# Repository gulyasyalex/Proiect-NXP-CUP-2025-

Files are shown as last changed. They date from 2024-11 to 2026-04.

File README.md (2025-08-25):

# Debix Smart RC Car — NXP Cup 2025
(For more Information visit Docs folder)
This project runs the **image processing** and **control logic** for the smart RC car using a **Debix Model B** with an **NXP i.MX 8M Plus** processor.  
It handles:
- Camera capture & processing (**OpenCV**)
- Pure Pursuit steering calculation
- TCP & Serial communication to the Teensy
- Optional TCP client to connect to your website for data/debug

---

## Project Structure

```
Proiect-NXP-CUP-2025-/
├── build/                # Build output for Debix C++ app
├── include/              # C++ header files and modules
├── src/                  # C++ source files
├── out/                  # (Optional) Generated output/logs
├── test/                 # Test code
├── Teensy-Code/          # Teensy firmware(separate build using Platformio)
├── VisionDebixTCP/       # Python TCP client
│   ├── TCPclient.py
├── .venv/                # Python virtual environment for TCP client
├── CMakeLists.txt        # C++ build configuration
├── debix-systemd-setup.txt # Systemd service setup instructions
└── README.md
```

---

## Requirements

**Debix Model B** running Linux  
**CMake** >= 3.15  
**g++** or Clang  
**OpenCV** installed  
**Python 3** (for TCP client)  
Teensy must be flashed separately with Platformio

---

## Build Instructions — C++ Debix App in command line

1. From the project root:
   cmake -S . -B build

2. Build the project:
   cmake --build build

3. The executable will be in `build/`:
   ./build/DEBIX

---

## Run Instructions

### ✅ Run C++ Debix App

1. Make sure:
   - USB camera is connected
   - Teensy is connected
   - ENABLE_TCP_SITE_DEBUG is 1 if you want web access / 0 if in race mode

2. Run your app:
   ./build/DEBIX

### ✅ Run Python TCP Client

1. Activate your Python virtual environment:
   source .venv/bin/activate

2. Go to your TCP client folder:
   cd VisionDebixTCP
   python TCPclient.py

---

## ⚡ Teensy Firmware

The `Teensy-Code/` folder holds your Teensy microcontroller code.  
Flash it separately using **PlatformIO**.

---

## ✅ Tips

- Use `config.h` for all kind of config settings.
- Check camera details with `v4l2-ctl --list-devices`.

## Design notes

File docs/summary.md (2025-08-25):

# Project Summary
I have a full thesis on this project in my native language. Online tools can easily translate all informations for better understanding. Thank you!
## Overview

This work presents the development of an autonomous vehicle for the NXP Cup competition, where the goal is to complete a predefined track without human intervention. The project combines both hardware components and custom-developed algorithms in order to achieve competitive performance.

For track detection, a camera mounted in the center of the car captures images in real time, processed using the OpenCV library. All image processing runs on the Debix Model B board, while a Teensy 4.0 microcontroller controls the actuators.

An important aspect of this work is the image processing pipeline (detailed in Section 4.3 of the thesis) and the use of the Bird’s Eye View technique, which improves perception of the surrounding environment. The main trajectory tracking algorithm is based on an enhanced version of Pure Pursuit (explained in Section 4.4), which relies on the midline of the track and the vehicle’s geometry. The improvement consists of dynamically adjusting the lookahead distance according to the vehicle’s speed and the curvature of the detected path.

Testing was conducted both on a custom-built track (with better grip than the competition’s) and on the official NXP Cup track. This difference in conditions initially affected system performance, but thanks to the interactive settings menu, parameters could be tuned on the day of the competition, resulting in satisfactory performance.

## Architecture

The system architecture is divided into two main components: hardware and software.

### Hardware Architecture

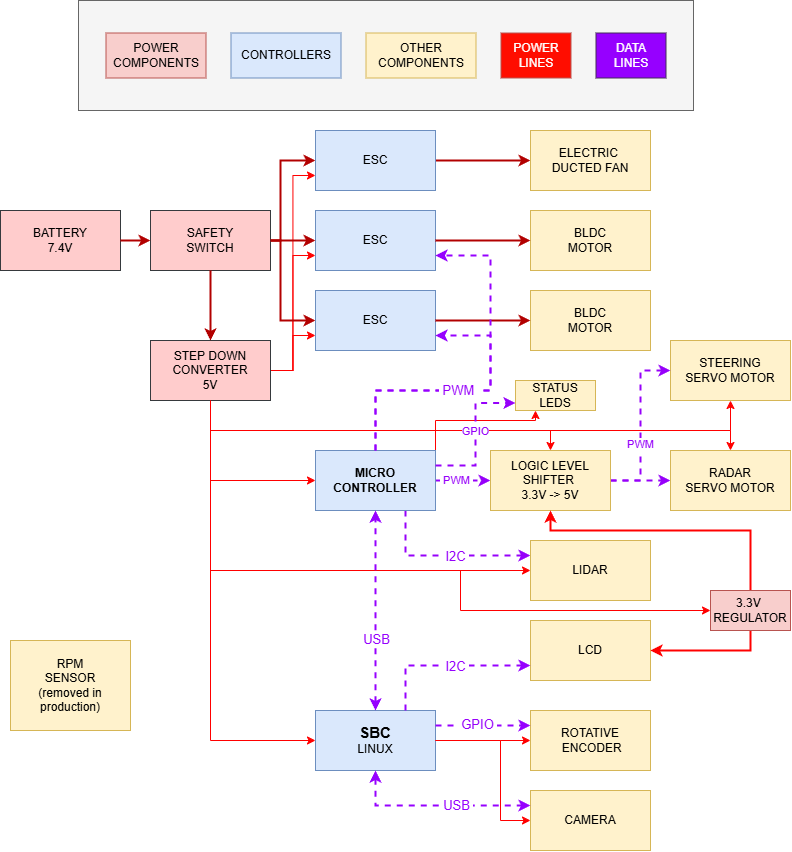
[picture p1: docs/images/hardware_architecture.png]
Hardware Architecture


Processing Unit: Debix Model B (NXP i.MX 8M Plus, ARM Cortex-A53 quad-core @ 1.6 GHz, integrated NPU up to 2.3 TOPS) running Ubuntu Linux.

Microcontroller: Teensy 4.0 used for real-time control of the servo motor and dual rear motors.

Actuators:
* Steering via SPT5613 servo motor implementing Ackermann geometry.
* Propulsion via two DC motors mounted on the rear axle.
* Additional thrust from an EDF (Electric Ducted Fan) for straight-line speed.

Sensors:
* USB UVC camera for track detection.
* LiDAR (infrared) for obstacle detection and finish-line sensing.
* Rotary encoder for speed feedback.
* OLED display + rotary encoder for interactive settings menu.

Power System: Li-Po battery with step-down converters for stable voltage supply.

### Software Architecture

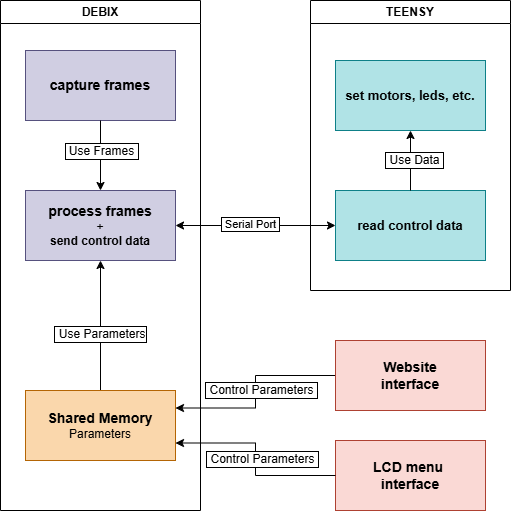
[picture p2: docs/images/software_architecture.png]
Software Architecture


The software stack is split across the Debix board and the Teensy microcontroller:

Debix Board (Linux):
* Image acquisition using OpenCV.
* Preprocessing pipeline: thresholding, skeletonization, line detection, polyline simplification, midline generation.
* Perspective transformation (Bird’s Eye View) for improved lane perception.
* Path tracking using Pure Pursuit with dynamic lookahead distance.
* TCP communication with Teensy for sending steering and speed commands.
* Interactive Python menu for adjusting parameters in real time (via shared memory and OLED display).

Teensy Microcontroller:
* Reads serial commands from the Debix.
* Generates PWM signals for the steering servo and rear motors.
* Safety features, including emergency remote stop and refresh rate control.

This modular architecture ensures real-time image processing on the Debix while leaving low-level actuator control to the Teensy, balancing performance and reliability.

## Algorithms

The software relies on a multi-stage pipeline for perception and control. The main steps are lane detection, Bird’s Eye View transformation, and path tracking with Pure Pursuit.

### Lane Detection

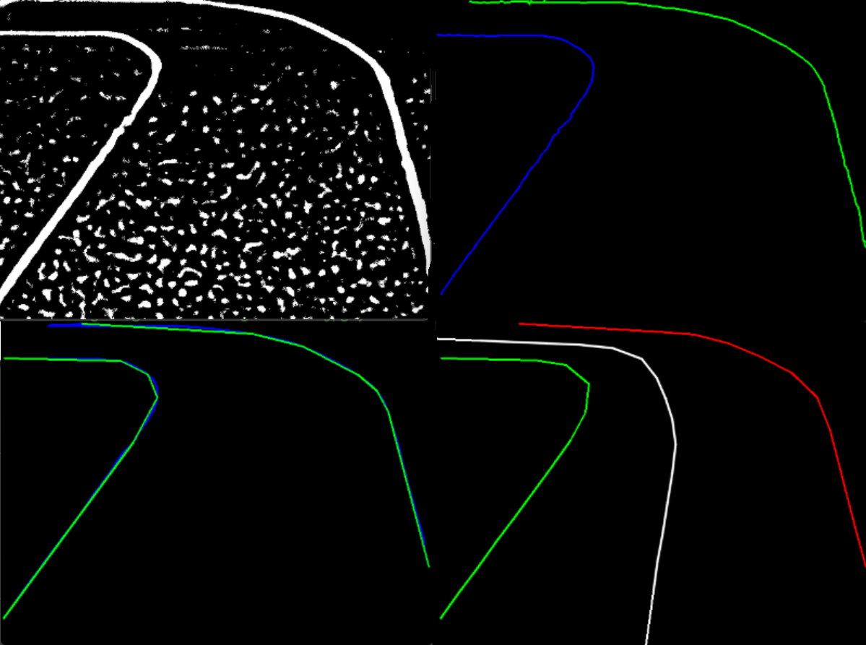
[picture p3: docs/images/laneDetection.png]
Lane Detection


The camera feed is processed in real time using OpenCV:
* Preprocessing – thresholding to isolate lane markings from the background.
* Skeletonization – reducing the lane shape to its central line for robustness.
* Line detection and simplification – converting the skeleton into a polyline with fewer points, reducing computational load.
* Midline generation – computing the midpoint between left and right lane boundaries to represent the drivable path.

This stage outputs a discrete midline of the track, represented as a set of points.

### Bird’s Eye View Transformation

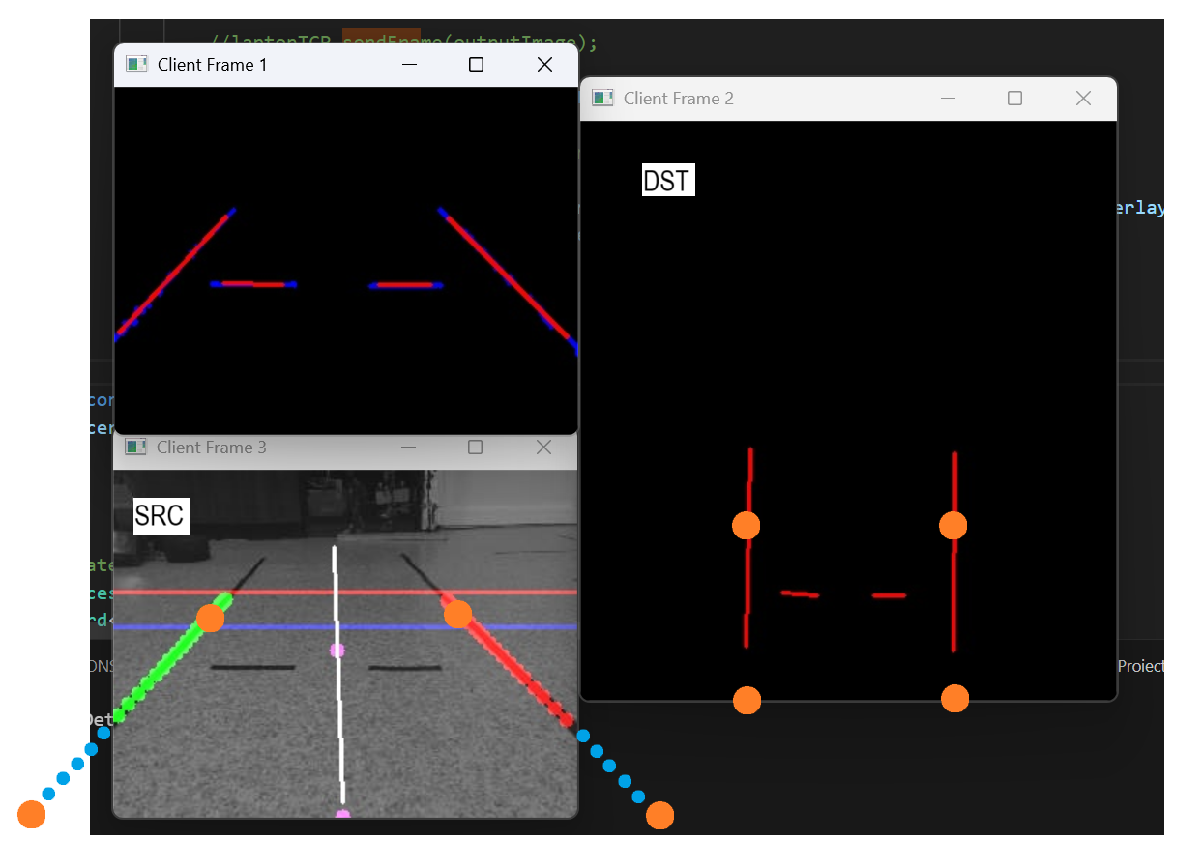
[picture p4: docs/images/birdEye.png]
Bird’s Eye View


To improve perception accuracy, a perspective transform is applied to obtain a Bird’s Eye View (top-down) of the track.

This reduces distortions from the forward-facing camera.
Curves and straight segments are easier to analyze in this perspective.
The transformation matrix is calibrated once for the camera position and then applied consistently during runtime.

### Pure Pursuit with Dynamic Lookahead

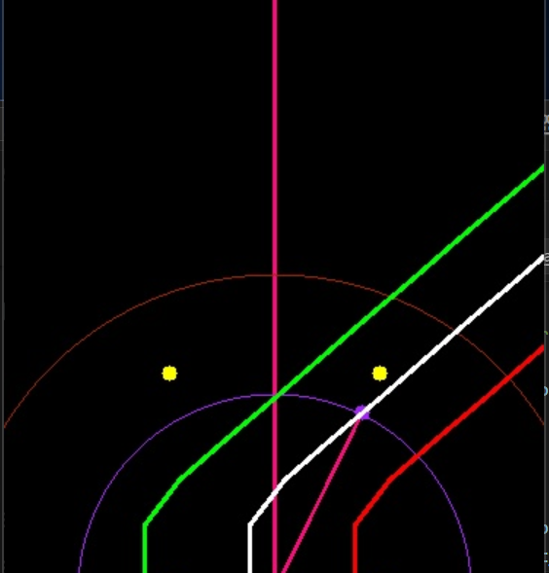
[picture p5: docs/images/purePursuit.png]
Pure Pursuit


Path tracking is implemented using an enhanced Pure Pursuit algorithm:
The algorithm selects a lookahead point on the midline, ahead of the car’s current position.
The steering angle is computed geometrically based on the curvature required to reach this point.
Dynamic lookahead distance:
* Increases with higher vehicle speed.
* Decreases for tighter curves (shorter radius).
This adaptation improves both stability on straights and maneuverability in curves.

The output is a steering command sent to the Teensy, while a separate speed control strategy adjusts motor power to balance agility and stability.

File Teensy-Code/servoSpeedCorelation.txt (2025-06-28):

Servo Write to Speed Mapping – Discussion Summary

Measured Data:
---------------
Servo write = 91:
   Speed = 0 cm/s (wheels do not move)

Servo write = 100:
   Speed ≈ 214 cm/s

Servo write = 110:
   Speed ≈ 493 cm/s

Servo write = 120:
   Speed ≈ 668 cm/s

------------------------------------------------------------
Step 1: Define a Shifted Variable

Since the wheels do not move at a servo write of 91, define:
    t = servo write - 91

This yields:
    t = 0   →   0 cm/s
    t = 9   →   214 cm/s
    t = 19  →   493 cm/s
    t = 29  →   668 cm/s

------------------------------------------------------------
Step 2: Fitting a Mathematical Formula

Assume that the speed can be modeled by a cubic polynomial (with no constant term, since when t = 0, speed = 0):

    Speed (cm/s) = A*t^3 + B*t^2 + C*t

Data Equations:
1. For t = 9:
      A*(9)^3 + B*(9)^2 + C*(9) = 214
2. For t = 19:
      A*(19)^3 + B*(19)^2 + C*(19) = 493
3. For t = 29:
      A*(29)^3 + B*(29)^2 + C*(29) = 668

Fitted (approximate) coefficients:
    A ≈ -0.02545
    B ≈ 0.929
    C ≈ 17.48

Thus, the forward mapping formula is:
    Speed (cm/s) ≈ -0.02545*t^3 + 0.929*t^2 + 17.48*t,  where t = servo write - 91

Checking the Formula:
----------------------
At servo write = 100:
   t = 100 - 91 = 9
   Speed ≈ -0.02545*(9^3) + 0.929*(9^2) + 17.48*9 ≈ 214 cm/s

At servo write = 110:
   t = 110 - 91 = 19
   Speed ≈ 493 cm/s

At servo write = 120:
   t = 120 - 91 = 29
   Speed ≈ 668 cm/s

------------------------------------------------------------
Step 3: Inverting the Relationship

To determine the required servo write for a desired speed (for example, 493 cm/s):

1. Start with the equation:
      -0.02545*t^3 + 0.929*t^2 + 17.48*t = v,
   where v is the desired speed (in cm/s).

2. Rearranged, the equation is:
      -0.02545*t^3 + 0.929*t^2 + 17.48*t - v = 0

For v = 493 cm/s, we know t = 19 (since 110 servo write gives 493 cm/s, and 110 - 91 = 19).

Once t is found, compute:
      servo write = t + 91

General Inversion Methods:
---------------------------
- Exact Method: Use the cubic formula (Cardano’s method) to solve for t.
- Numerical Method: Use an iterative numerical method (e.g., Newton–Raphson) to solve for t.
- Lookup Table: For a limited range, pre-calculate values and use a lookup table.

------------------------------------------------------------
Summary:
--------
Forward Mapping:
   1. Calculate t = servo write - 91.
   2. Compute Speed (cm/s) as:
         v ≈ -0.02545*t^3 + 0.929*t^2 + 17.48*t

Inverse Mapping:
   1. Given a desired speed v, solve:
         -0.02545*t^3 + 0.929*t^2 + 17.48*t - v = 0
      for t.
   2. Then, compute:
         servo write = t + 91

Example:
   For a desired speed of 493 cm/s:
      t = 19 (since 493 cm/s is achieved at t = 19)
      Therefore, servo write = 19 + 91 = 110.

Cardano’s Formula

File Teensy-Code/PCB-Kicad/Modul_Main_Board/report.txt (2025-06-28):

Plotted to 'D:\NXP_CUP_2024\Modul_LCD\NXP_CUP_Main_Board\Modul_LCD-F_Cu.gbr'.
Plotted to 'D:\NXP_CUP_2024\Modul_LCD\NXP_CUP_Main_Board\Modul_LCD-B_Cu.gbr'.
Plotted to 'D:\NXP_CUP_2024\Modul_LCD\NXP_CUP_Main_Board\Modul_LCD-F_Paste.gbr'.
Plotted to 'D:\NXP_CUP_2024\Modul_LCD\NXP_CUP_Main_Board\Modul_LCD-B_Paste.gbr'.
Plotted to 'D:\NXP_CUP_2024\Modul_LCD\NXP_CUP_Main_Board\Modul_LCD-F_Silkscreen.gbr'.
Plotted to 'D:\NXP_CUP_2024\Modul_LCD\NXP_CUP_Main_Board\Modul_LCD-B_Silkscreen.gbr'.
Plotted to 'D:\NXP_CUP_2024\Modul_LCD\NXP_CUP_Main_Board\Modul_LCD-F_Mask.gbr'.
Plotted to 'D:\NXP_CUP_2024\Modul_LCD\NXP_CUP_Main_Board\Modul_LCD-B_Mask.gbr'.
Plotted to 'D:\NXP_CUP_2024\Modul_LCD\NXP_CUP_Main_Board\Modul_LCD-Edge_Cuts.gbr'.
Created Gerber job file 'D:\NXP_CUP_2024\Modul_LCD\NXP_CUP_Main_Board\Modul_LCD-job.gbrjob'.
Info: Done.

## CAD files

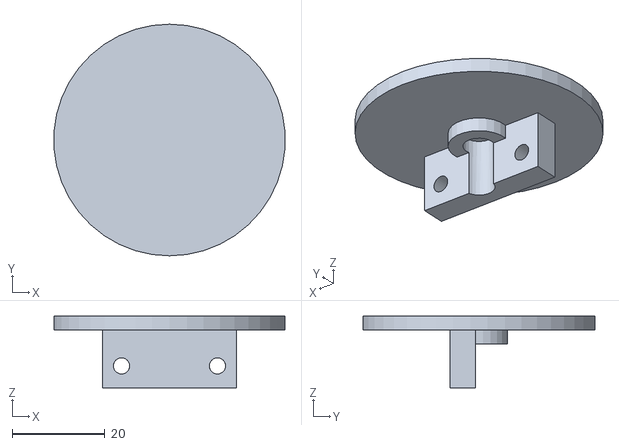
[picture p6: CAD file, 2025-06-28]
Teensy-Code/3D Print/Camera/TopCameraStandSafetyProtection/TopCameraStandSafetyProtection_main.stl
49.9 x 50.0 x 15.5

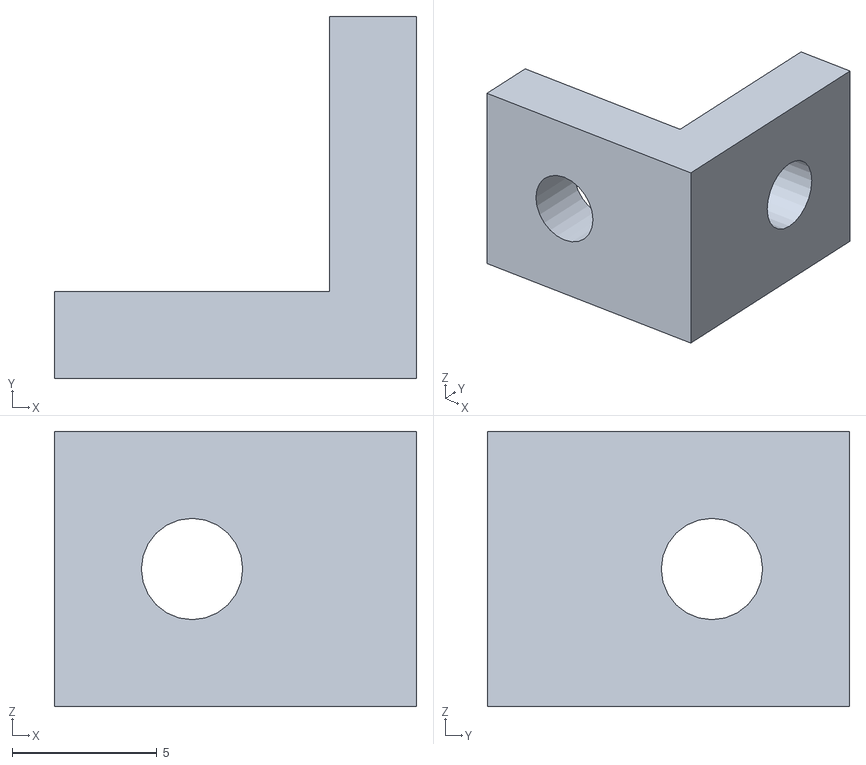
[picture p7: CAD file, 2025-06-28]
Teensy-Code/3D Print/Camera/Camera stand longitudinal support/Camera stand longitudinal support_chassis joint.stl
12.5 x 12.5 x 9.50

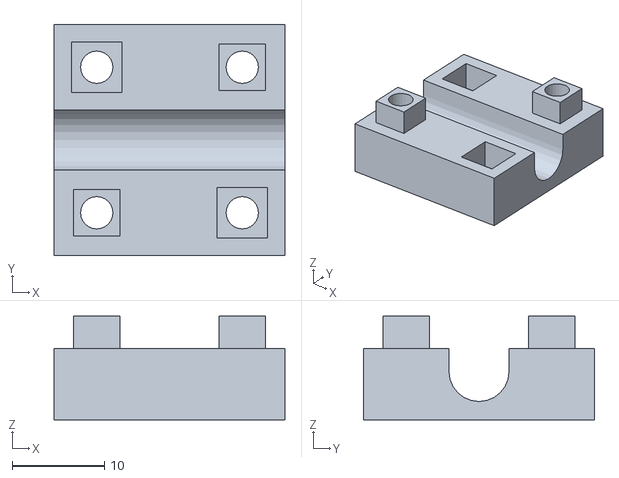
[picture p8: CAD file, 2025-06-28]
Teensy-Code/3D Print/Camera/Camera stand/90 degrees joint/90 degrees joint_1.stl
25.0 x 25.0 x 11.2

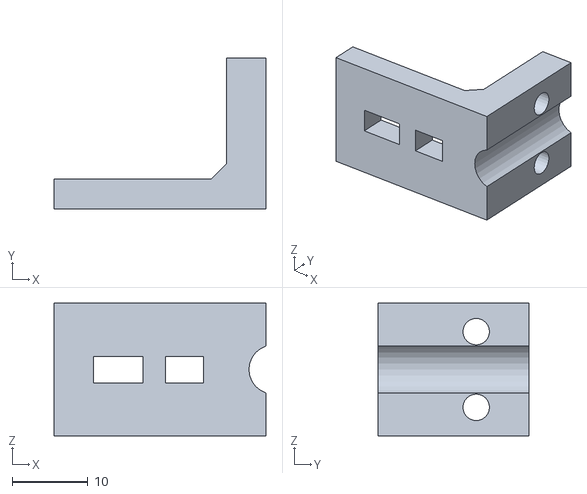
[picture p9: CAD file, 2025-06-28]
Teensy-Code/3D Print/Camera/Camera stand/90 degrees short L/90 degrees short L.stl
28.0 x 20.0 x 17.5

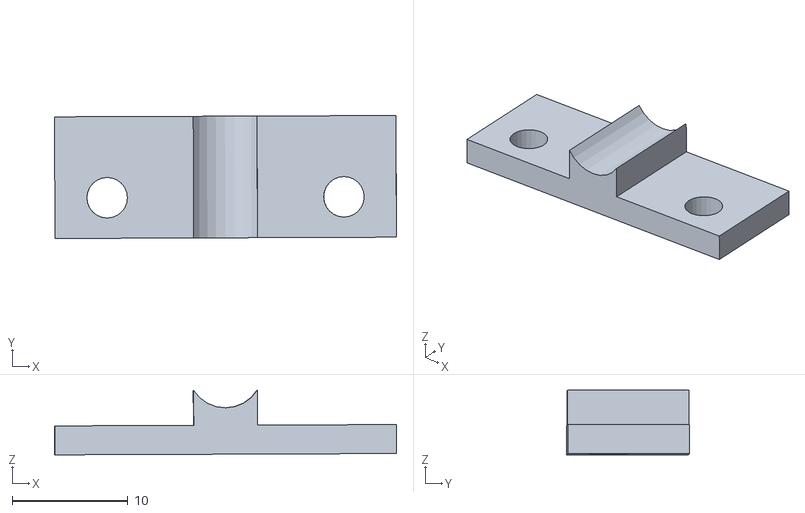
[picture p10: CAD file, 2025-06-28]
Teensy-Code/3D Print/Camera/Camera stand/round joint/round joint_back.stl
29.5 x 10.6 x 5.59

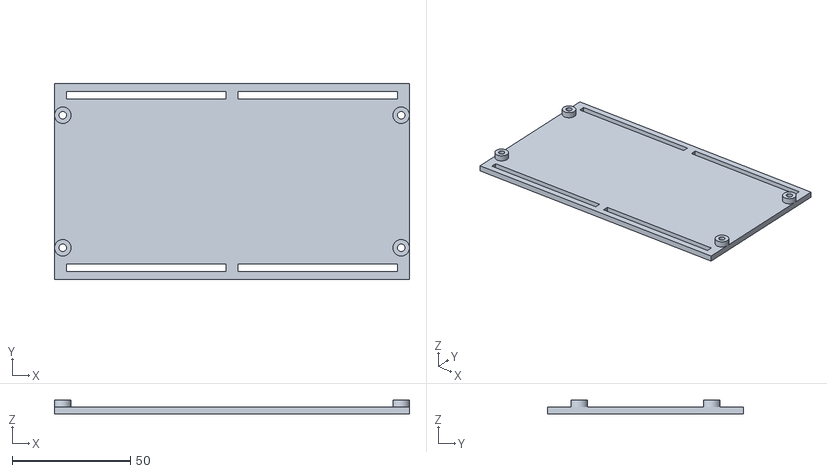
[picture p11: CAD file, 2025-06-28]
Teensy-Code/3D Print/CarBodyAdditionalMounting/MountingPlateLCD/MountingPlateLCD.stl
150.0 x 83.0 x 6.00

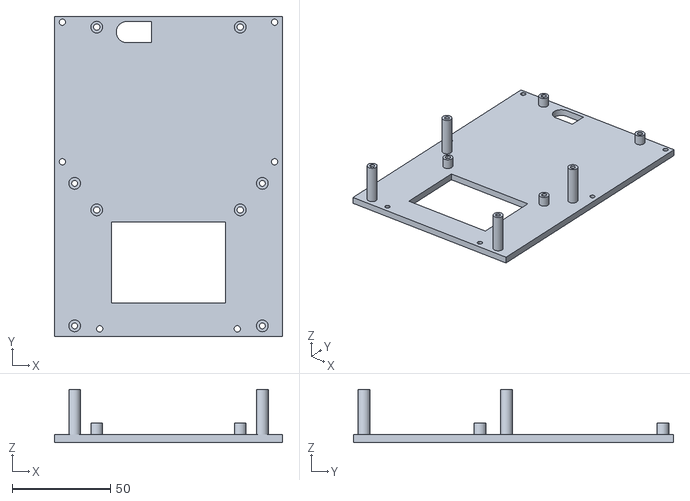
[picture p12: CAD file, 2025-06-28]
Teensy-Code/3D Print/CarBodyAdditionalMounting/MountingPlatePCBs/MountingPlatePCBs.stl
116.0 x 163.0 x 27.0

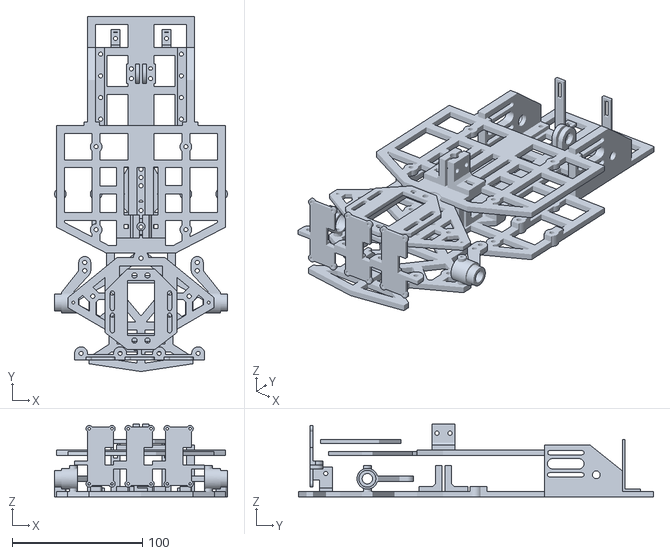
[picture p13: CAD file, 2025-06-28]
Teensy-Code/3D Print/CarModel/CarModel.stl
133.0 x 273.0 x 56.0

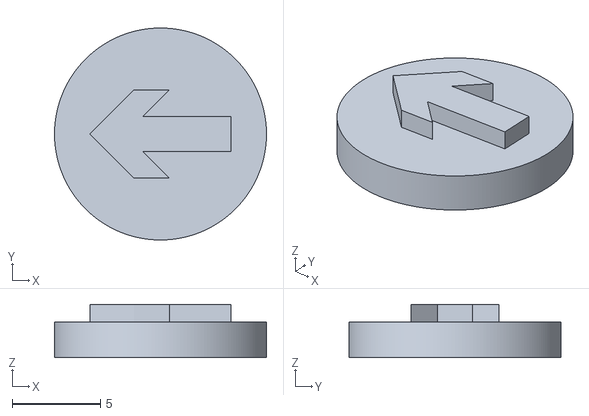
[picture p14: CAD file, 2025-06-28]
Teensy-Code/3D Print/MenuButtons/Left.stl
12.0 x 12.0 x 3.00

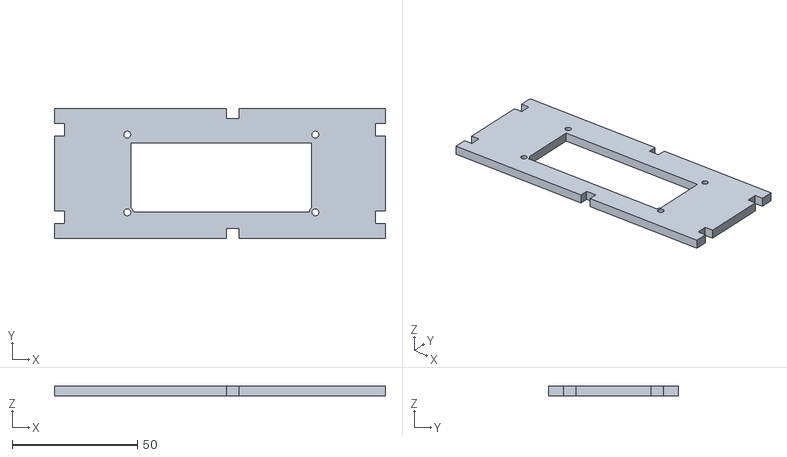
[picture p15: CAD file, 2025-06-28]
Teensy-Code/3D Print/NXPCupTimer/CapacTimer.stl
132.0 x 52.0 x 4.00

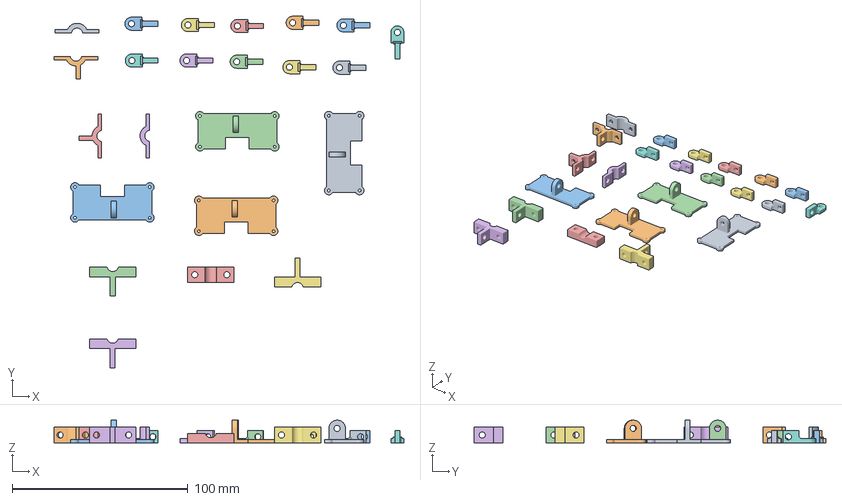
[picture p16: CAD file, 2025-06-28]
Teensy-Code/3D Print/spareparts2.3mf
199.0 x 199.9 x 13.0 mm
Ultrasonic distance sensor stand_main.stl(3)
Ultrasonic distance sensor stand_main.stl(2)
Ultrasonic distance sensor stand_main.stl(1)
Ultrasonic distance sensor stand_main.stl
camera joint_round_1.stl(1)
camera joint_round_2.stl(1)
camera joint_arm.stl(10)
camera joint_arm.stl(9)
camera joint_arm.stl(8)
camera joint_arm.stl(7)
camera joint_arm.stl(6)
camera joint_arm.stl(5)
camera joint_arm.stl(4)
camera joint_arm.stl(3)
camera joint_arm.stl(2)
camera joint_arm.stl(1)
camera joint_round_2.stl
camera joint_round_1.stl
camera joint_arm.stl
CE3E3V2_Camera stand longitudinal support_vertical pipe joint.3mf
CE3E3V2_Camera stand longitudinal support_vertical pipe joint.3mf(1)
CE3E3V2_Camera stand longitudinal support_vertical pipe joint.3mf(2)
CE3E3V2_Camera stand longitudinal support_vertical pipe joint.3mf(3)

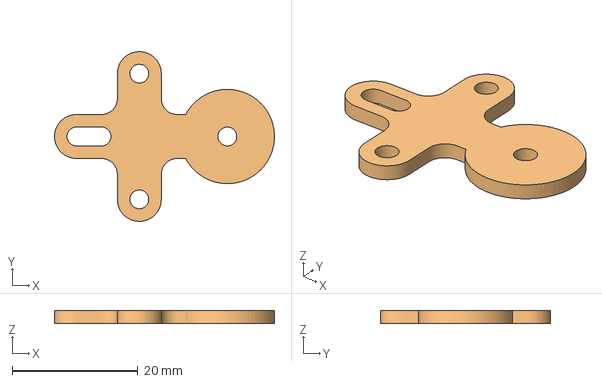
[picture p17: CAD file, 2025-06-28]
Teensy-Code/3D Print/SteeringRodServoAttachment/SteeringRodServoAttachment.3mf
35.0 x 27.0 x 2.00 mm
SteeringRodServoAttachment.stl x 2

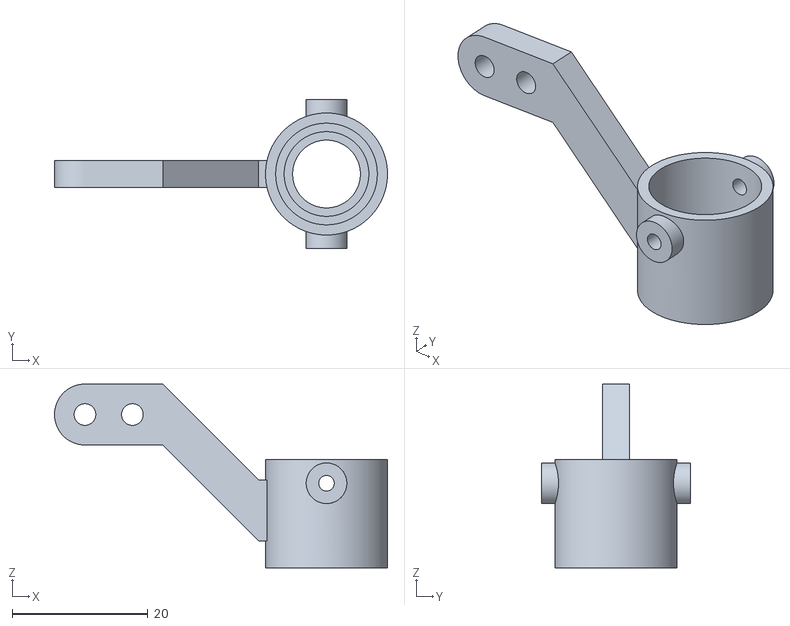
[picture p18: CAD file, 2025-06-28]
Teensy-Code/3D Print/WheelArm12by4mm/WheelArm12by4mm.stl
49.1 x 22.0 x 27.1

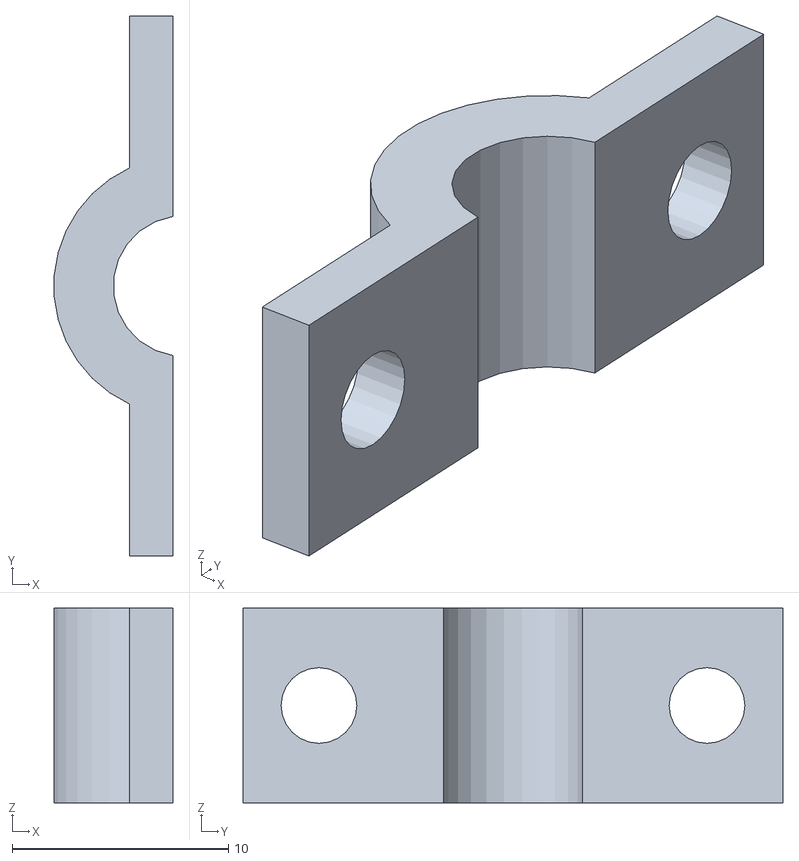
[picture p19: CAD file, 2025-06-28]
Teensy-Code/3D Print/Camera/Camera joint/camera joint_round_2.stl
5.48 x 25.0 x 9.00

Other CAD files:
Teensy-Code/3D Print/Camera/Camera joint/camera joint.dwg
Teensy-Code/3D Print/Camera/Camera stand longitudinal support/Camera stand longitudinal support_longitudinal pipe joint_1.stl
Teensy-Code/3D Print/Camera/Camera stand/90 degrees joint/90 degrees joint.dwg
Teensy-Code/3D Print/Camera/Camera stand/round joint/round joint_arm.stl
Teensy-Code/3D Print/Archived/Back Support/SuportSpate1 v1.stl
Teensy-Code/3D Print/Archived/Button Support/butonNXP v1.stl
Teensy-Code/3D Print/Archived/Front Support/SuportFata1 v1.stl
Teensy-Code/3D Print/Archived/Menu Support/MenuSupport.dwg
Teensy-Code/3D Print/Archived/Menu Support/MenuSupport_cover_back.stl
Teensy-Code/3D Print/Archived/Menu Support/MenuSupport_cover_buttons.stl
Teensy-Code/3D Print/Archived/Menu Support/MenuSupport_cover_front.stl
Teensy-Code/3D Print/Archived/Menu Support/MenuSupport_prindere_teava.stl
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

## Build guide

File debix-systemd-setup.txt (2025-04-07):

Debix Auto-Start Setup Using systemd (Working Version)

Actual Executable Path:
/home/debix/Documents/Proiect-NXP-CUP-2025-/build/DEBIX

chmod +x /home/debix/Documents/Proiect-NXP-CUP-2025-/build/DEBIX

1. Create Systemd Service File
sudo nano /etc/systemd/system/debix-app.service
Paste the following:
[Unit]
Description=Start NXP CUP setup at boot
After=network.target

[Service]
ExecStart=/home/debix/Documents/Proiect-NXP-CUP-2025-/build/DEBIX
WorkingDirectory=/home/debix/Documents/Proiect-NXP-CUP-2025-
StandardOutput=journal
StandardError=journal
Restart=always
User=debix

[Install]
WantedBy=multi-user.target

2. Reload and Enable the Service

sudo systemctl daemon-reexec
sudo systemctl daemon-reload
sudo systemctl enable debix-app.service
sudo systemctl start debix-app.service

3. Test and Debug
Live logs:
    journalctl -u debix-app.service -f
Status check:
    systemctl status debix-app.service
Stop:
    sudo systemctl stop debix-app.service
Restart:
    sudo systemctl restart debix-app.service
Disable auto-start:
    sudo systemctl disable debix-app.service
Re-enable auto-start:
    sudo systemctl enable debix-app.service

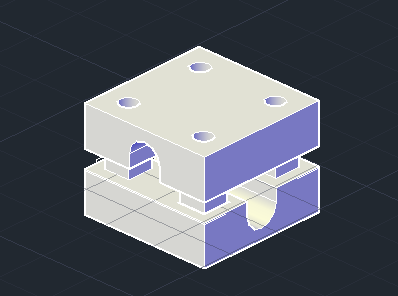
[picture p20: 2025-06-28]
Teensy-Code/3D Print/Camera/Camera stand/90 degrees joint/image.PNG

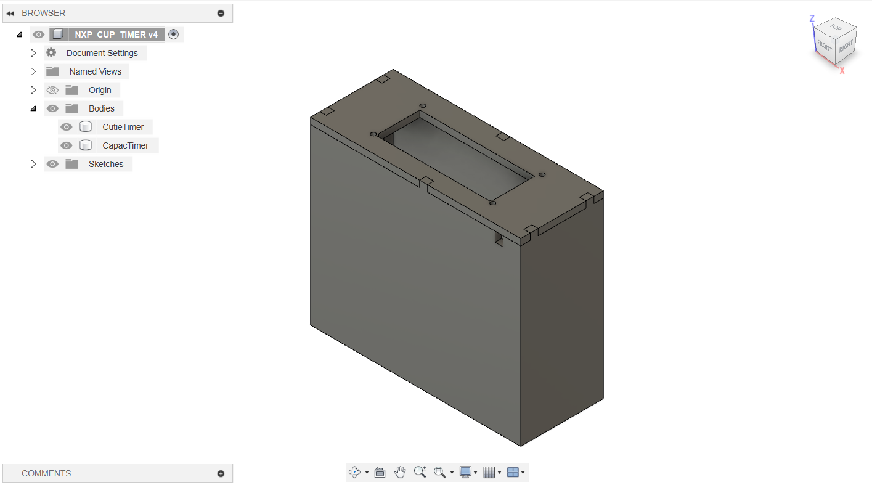
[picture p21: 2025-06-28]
Teensy-Code/3D Print/NXPCupTimer/NXP_CUP_TIMER.PNG

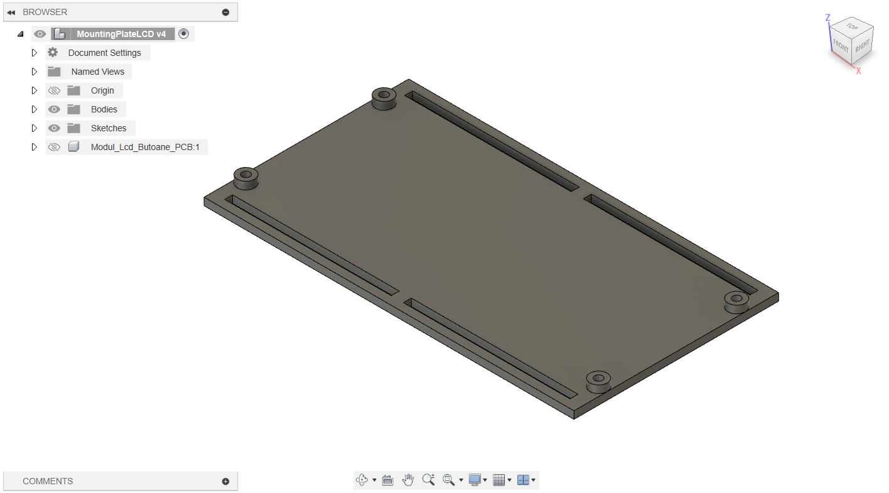
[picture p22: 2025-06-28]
Teensy-Code/3D Print/CarBodyAdditionalMounting/MountingPlateLCD/MountingPlateLCD.PNG

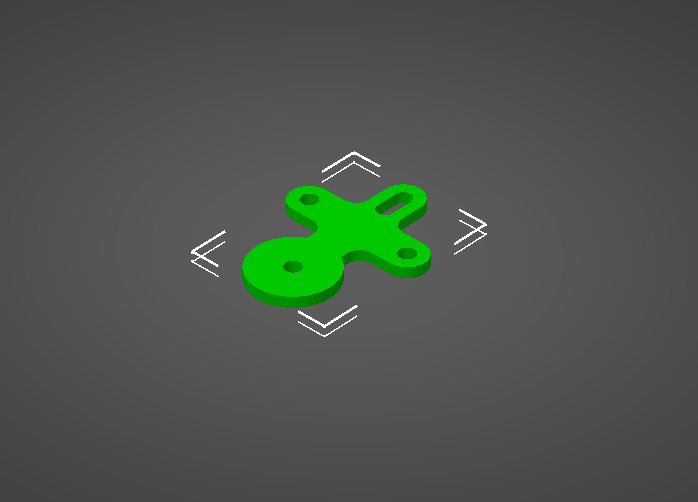
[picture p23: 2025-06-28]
Teensy-Code/3D Print/SteeringRodServoAttachment/SteeringRodServoAttachment.png

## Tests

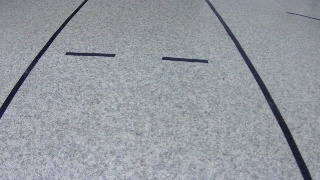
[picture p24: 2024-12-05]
testImages/imagine12022024_03.jpg

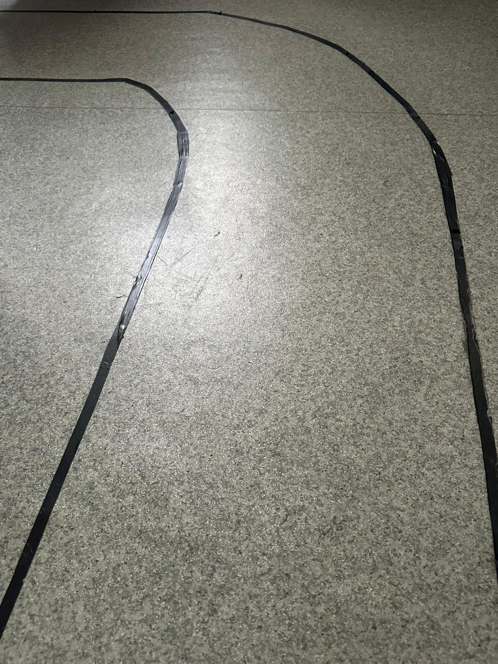
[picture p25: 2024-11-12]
testImages/imagineSala1.jpg

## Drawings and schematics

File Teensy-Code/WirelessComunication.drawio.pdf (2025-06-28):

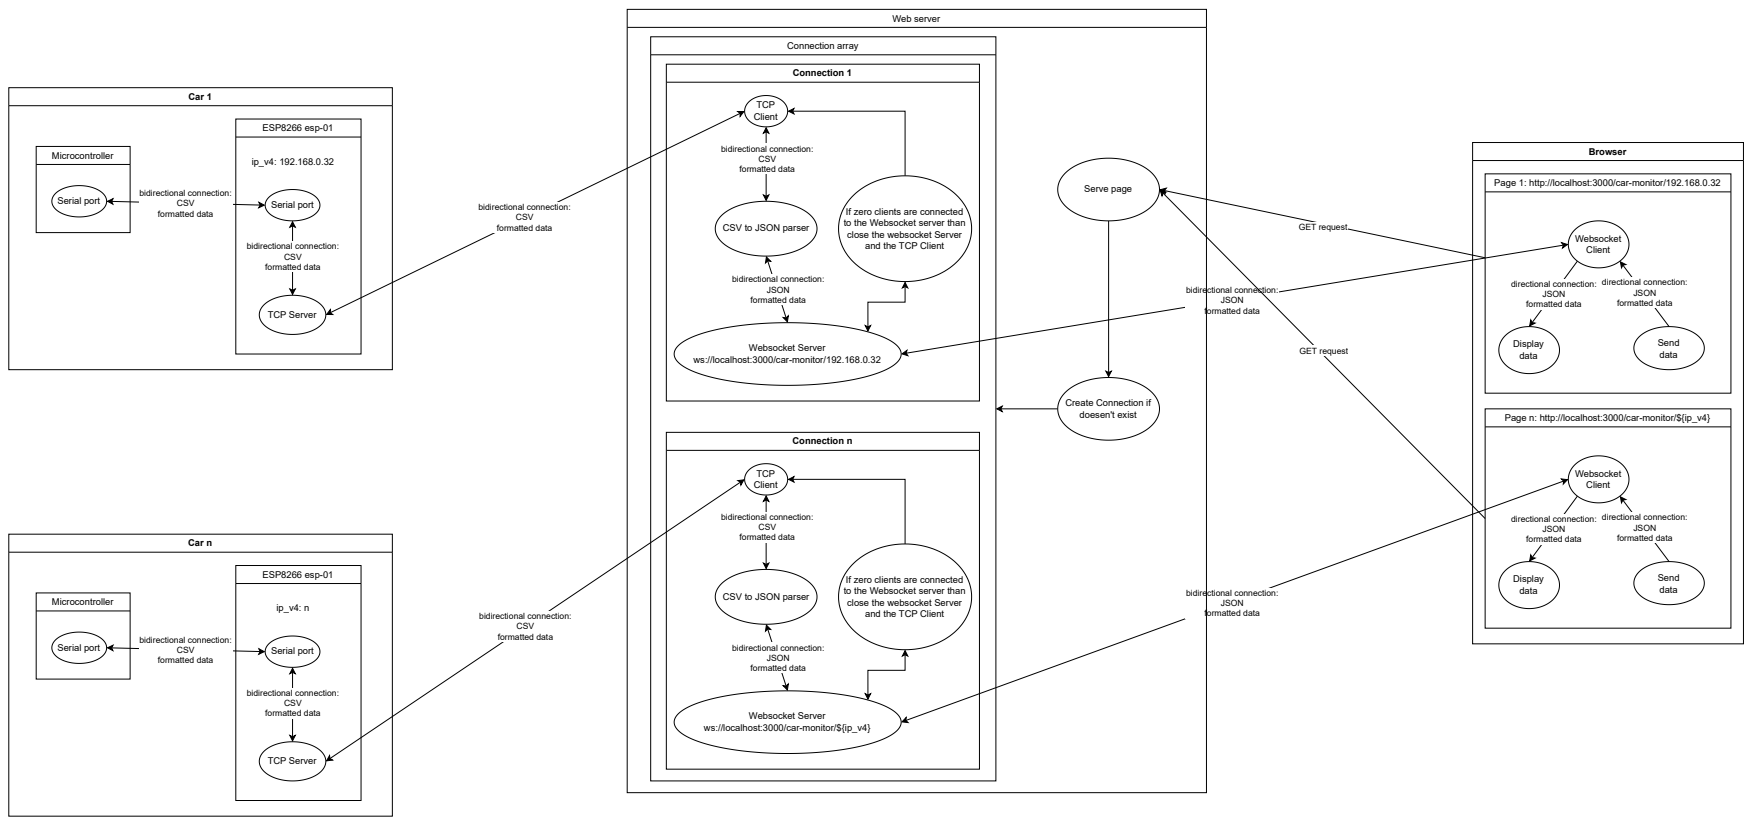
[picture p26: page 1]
bidirectional connection: CSV formatted data; bidirectional connection: JSON formatted data; Car n; ESP8266 esp-01; TCP Server; Serial port; ip_v4: n Microcontroller; Browser; Websocket Client; Display data; Send data; directional connection: JSON formatted data; Web server; Connection array; Connection n; TCP Client; Websocket Server; Connection 1; Serve page; Car 1; ip_v4: 192.168.0.32 Microcontroller; GET request

Page 1: http://localhost:3000/car-monitor/192.168.0.32

If zero clients are connected
to the Websocket server than
close the websocket Server
and the TCP Client

CSV to JSON parser

ws://localhost:3000/car-monitor/192.168.0.32

Create Connection if
doesen't exist

Page n: http://localhost:3000/car-monitor/${ip_v4}

ws://localhost:3000/car-monitor/${ip_v4}

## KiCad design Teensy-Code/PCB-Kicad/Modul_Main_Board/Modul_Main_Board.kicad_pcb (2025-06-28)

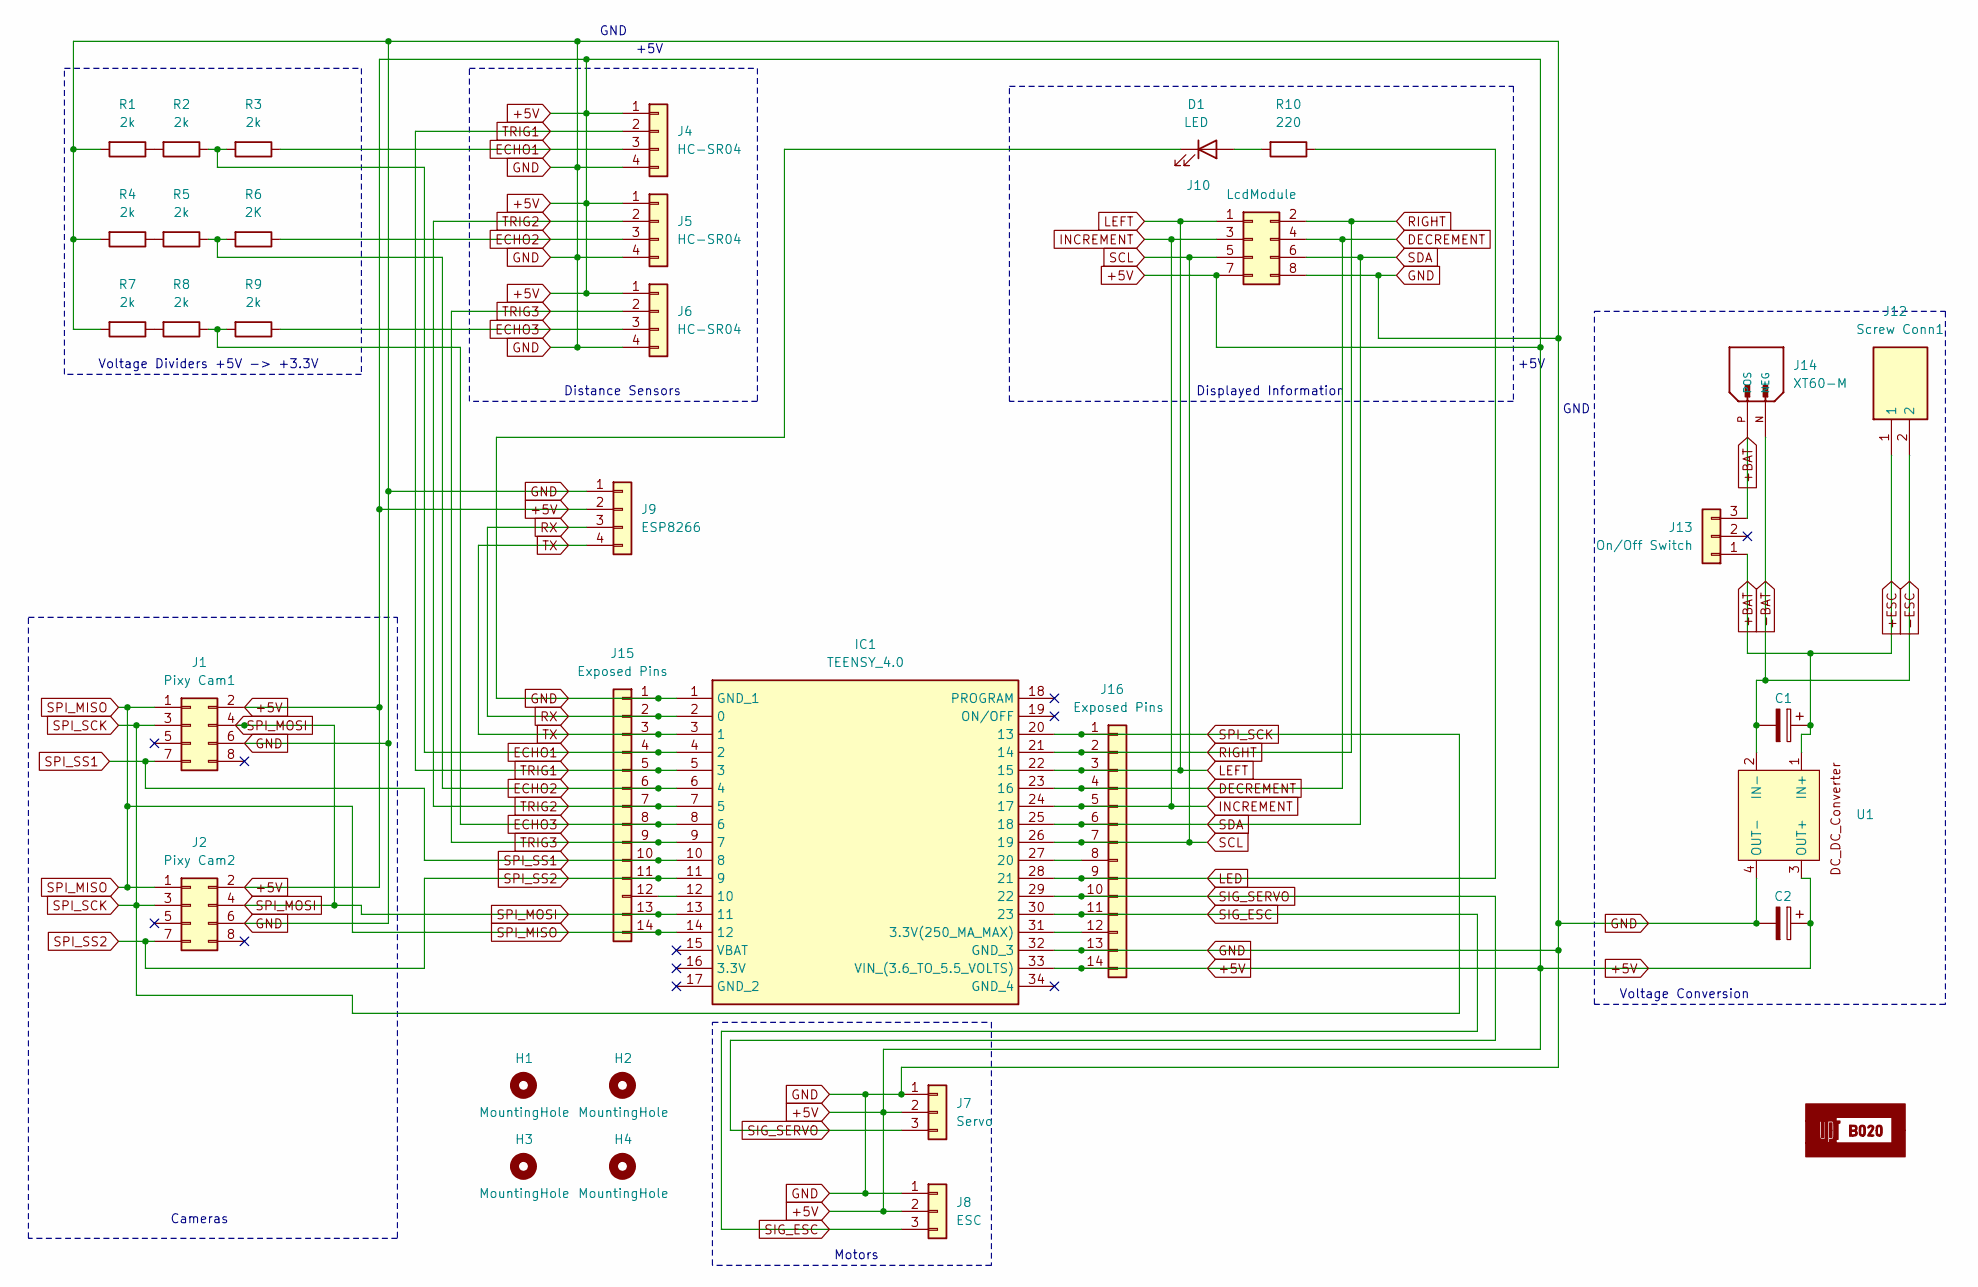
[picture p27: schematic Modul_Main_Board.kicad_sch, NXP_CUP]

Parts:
C1, C2: CP_Radial_D10.0mm_P5.00mm
D1: LED; JST_XH_B2B-XH-A_1x02_P2.50mm_Vertical
H1, H2, H3, H4: MountingHole; MountingHole_3.2mm_M3
IC1: TEENSY_4.0; TEENSY40_1; Manufacturer_Part_Number TEENSY 4.0
J1: Pixy Cam1; IDC-Header_2x04_P2.54mm_Vertical
J2: Pixy Cam2; IDC-Header_2x04_P2.54mm_Vertical
J4, J5, J6: HC-SR04; JST_XH_B4B-XH-A_1x04_P2.50mm_Vertical
J7: Servo; PinHeader_1x03_P2.54mm_Vertical
J8: ESC; JST_XH_B3B-XH-A_1x03_P2.50mm_Vertical
J9: ESP8266; PinSocket_1x04_P2.54mm_Vertical
J10: LcdModule; IDC-Header_2x04_P2.54mm_Vertical
J12: Screw Conn1; KF3012P; Manufacturer_Part_Number KF301-2P
J13: On/Off Switch; PinHeader_1x03_P2.54mm_Vertical
J14: XT60-M; AMASS_XT60-M; PARTREV V1.2
J15, J16: Exposed Pins; PinHeader_1x14_P2.54mm_Vertical
R1, R2, R3, R4, R5, R7, R8, R9: 2k; R_Axial_DIN0411_L9.9mm_D3.6mm_P12.70mm_Horizontal
R6: 2K; R_Axial_DIN0411_L9.9mm_D3.6mm_P12.70mm_Horizontal
R10: 220; R_Axial_DIN0411_L9.9mm_D3.6mm_P12.70mm_Horizontal
U1: XL6009

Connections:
+5V: C2.1, IC1.33 (VIN_(3.6_TO_5.5_VOLTS)), J1.2, J2.2, J4.1, J5.1, J6.1, J7.2, J8.2, J9.2, J10.7, J16.14, U1.3 (OUT+)
+BAT: C1.1, J12.1, J13.1, J13.3, J14.P (POS), U1.1 (IN+)
-BAT: C1.2, J12.2, J14.N (NEG), U1.2 (IN-)
DECREMENT: IC1.23 (16), J10.4, J16.4
ECHO1: IC1.4 (2), J4.3, J15.4, R2.1, R3.1, R3.2
ECHO2: IC1.6 (4), J5.3, J15.6, R5.1, R6.1, R6.2
ECHO3: IC1.8 (6), J6.3, J15.8, R8.1, R9.1, R9.2
GND: C2.2, D1.1 (K), IC1.1 (GND_1), IC1.32 (GND_3), J1.6, J2.6, J4.4, J5.4, J6.4, J7.1, J8.1, J9.1, J10.8, J15.1, J16.13, R1.2, R4.2, R7.2, U1.4 (OUT-)
INCREMENT: IC1.24 (17), J10.3, J16.5
LED: IC1.28 (21), J16.9, R10.1
LEFT: IC1.22 (15), J10.1, J16.3
unnamed: D1.2 (A), R10.2
unnamed: IC1.31 (3.3V(250_MA_MAX)), J16.12
unnamed: IC1.12 (10), J15.12
unnamed: IC1.27 (20), J16.8
unnamed: R1.1, R2.2
unnamed: R4.1, R5.2
unnamed: R7.1, R8.2
RIGHT: IC1.21 (14), J10.2, J16.2
RX: IC1.2 (0), J9.3, J15.2
SCL: IC1.26 (19), J10.5, J16.7
SDA: IC1.25 (18), J10.6, J16.6
SIG_ESC: IC1.30 (23), J8.3, J16.11
SIG_SERVO: IC1.29 (22), J7.3, J16.10
SPI_MISO: IC1.14 (12), J1.1, J2.1, J15.14
SPI_MOSI: IC1.13 (11), J1.4, J2.4, J15.13
SPI_SCK: IC1.20 (13), J1.3, J2.3, J16.1
SPI_SS1: IC1.10 (8), J1.7, J15.10
SPI_SS2: IC1.11 (9), J2.7, J15.11
TRIG1: IC1.5 (3), J4.2, J15.5
TRIG2: IC1.7 (5), J5.2, J15.7
TRIG3: IC1.9 (7), J6.2, J15.9
TX: IC1.3 (1), J9.4, J15.3

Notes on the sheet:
+5V
GND
Voltage Conversion
Voltage Dividers +5V -> +3.3V
GND
+5V
Motors
Distance Sensors
Displayed Information
Cameras

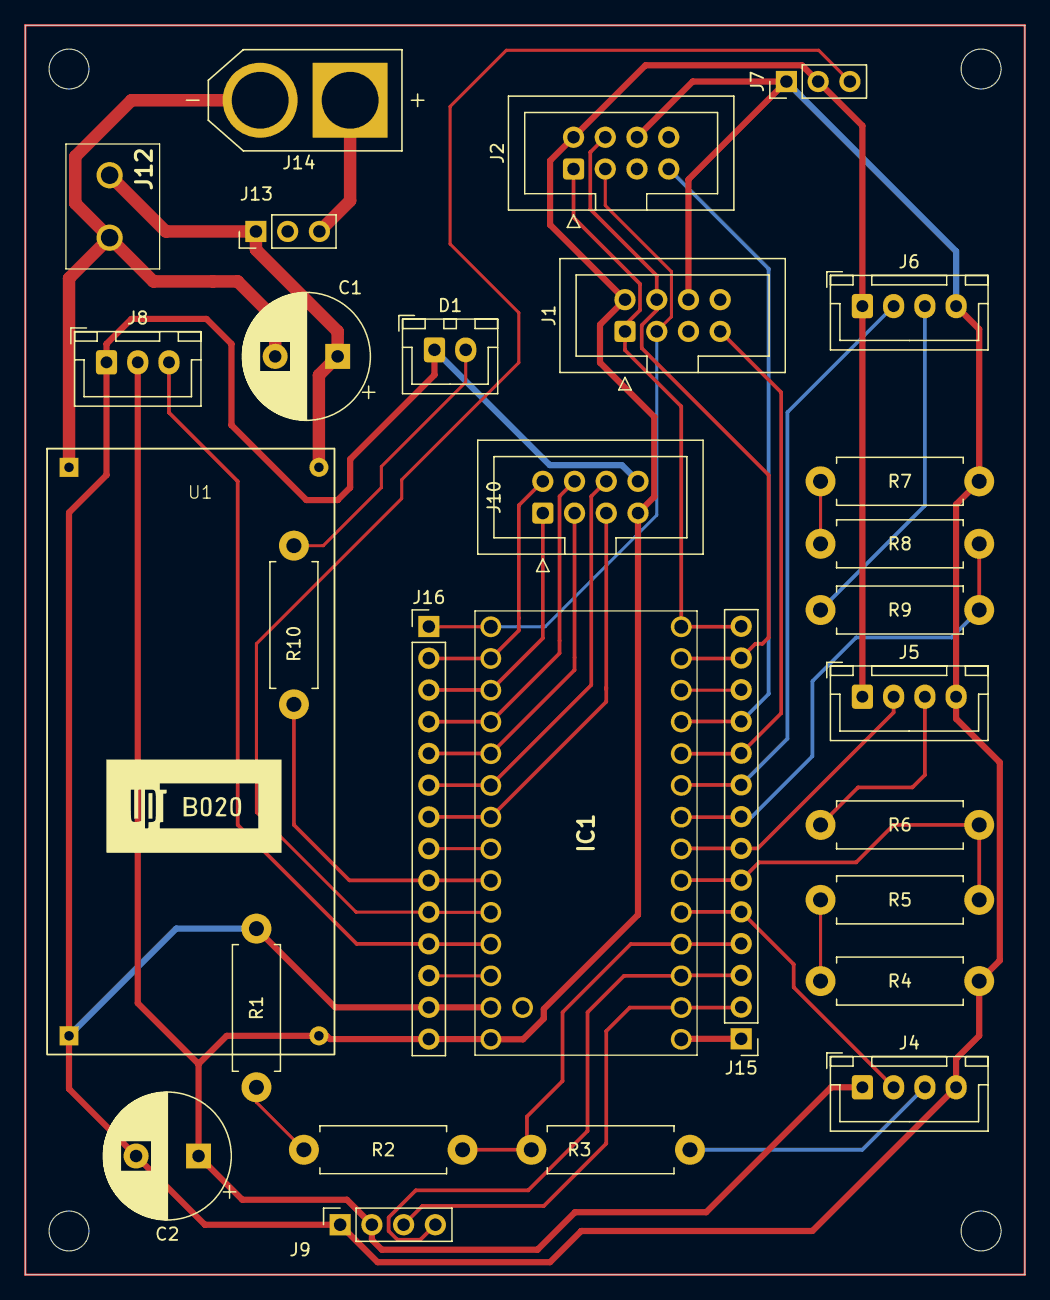
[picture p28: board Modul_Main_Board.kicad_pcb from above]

Board: 2 copper layers, 80.0 x 100.0 mm, 33 parts (0 on the bottom side), 33 nets.

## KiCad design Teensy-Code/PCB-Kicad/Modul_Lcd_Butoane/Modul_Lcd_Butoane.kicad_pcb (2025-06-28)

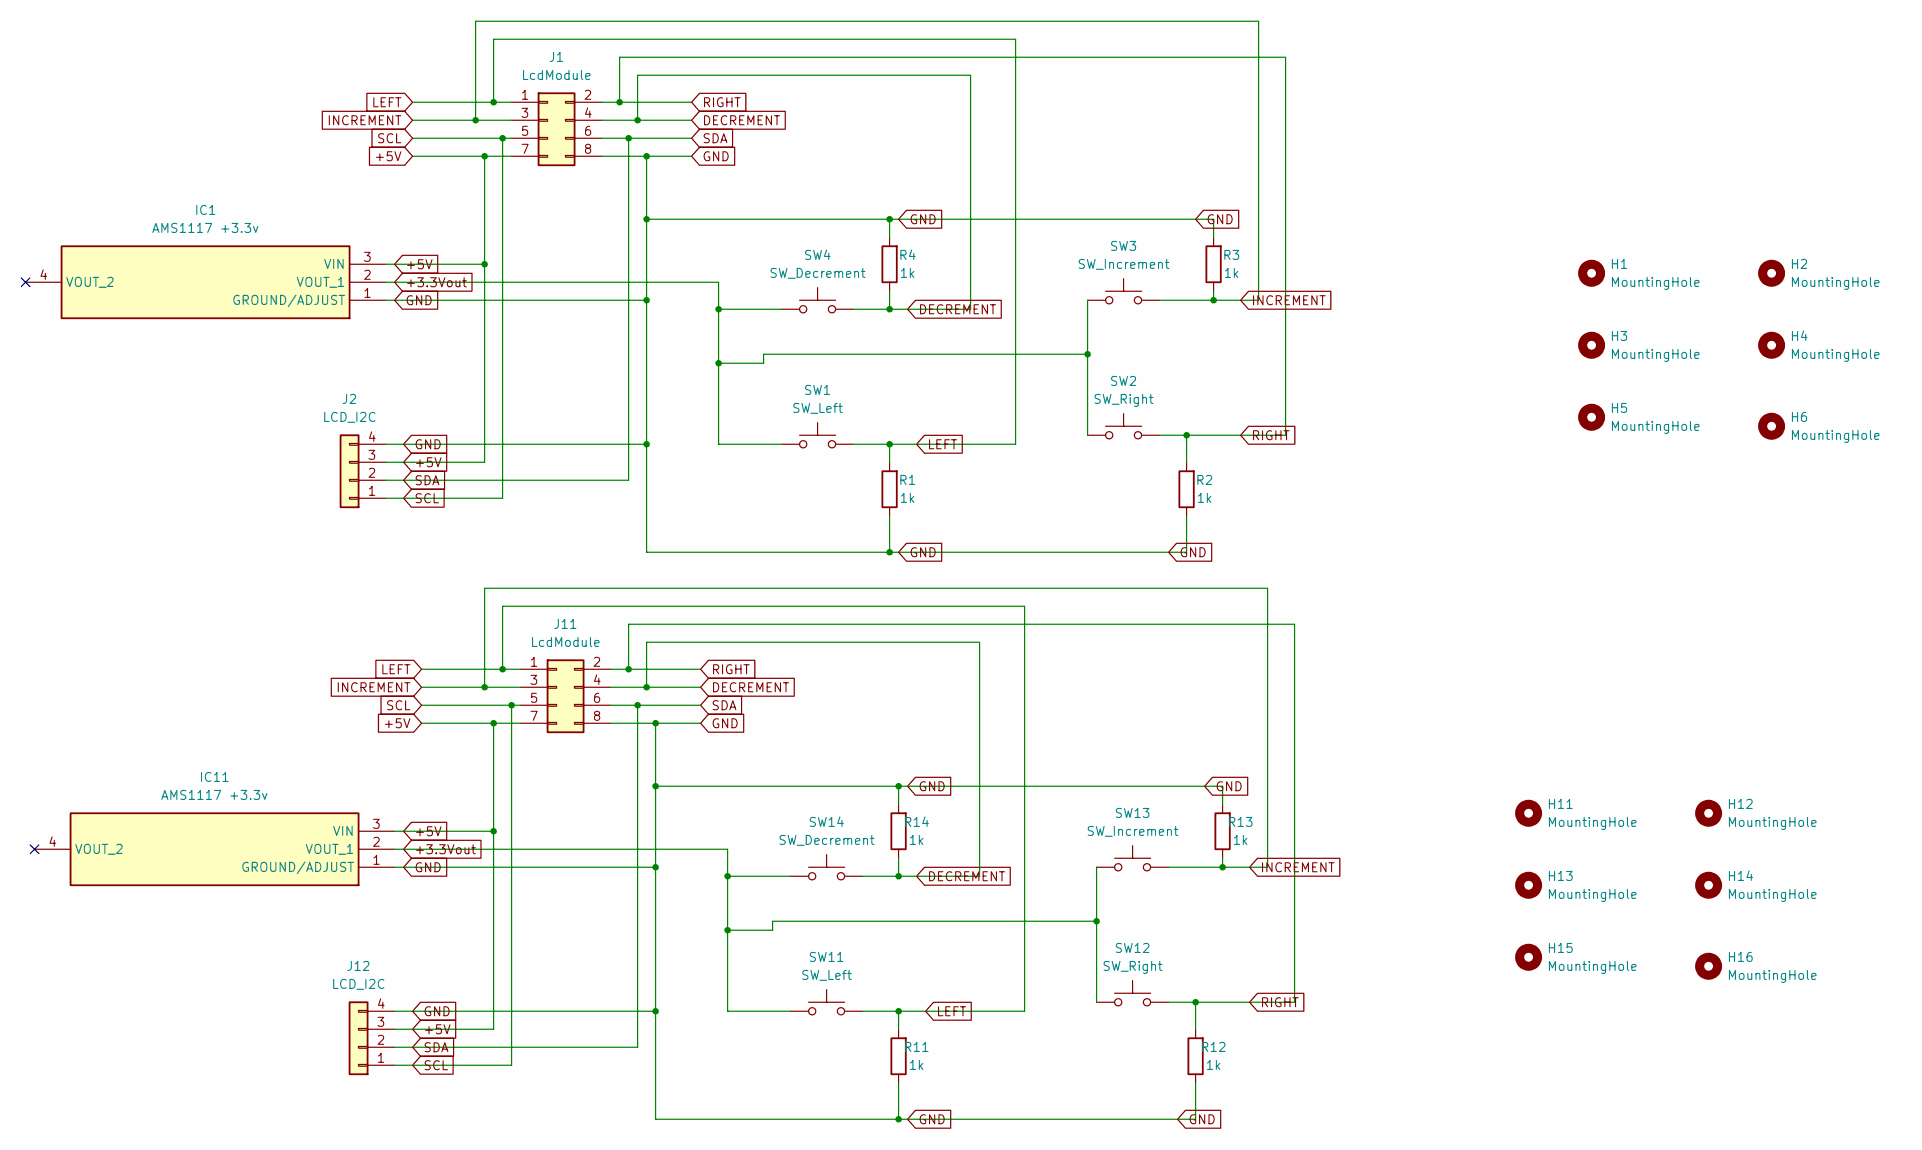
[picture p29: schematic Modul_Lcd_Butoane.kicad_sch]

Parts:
H1, H2, H3, H4, H5, H6, H11, H12, H13, H14, H15, H16: MountingHole; MountingHole_3.2mm_M3
IC1, IC11: AMS1117 +3.3v; SOT229P700X180-4N; Manufacturer_Part_Number ams1117-3.3v
J1, J11: LcdModule; IDC-Header_2x04_P2.54mm_Vertical
J2, J12: LCD_I2C; PinSocket_1x04_P2.54mm_Horizontal
R1, R2, R3, R4, R11, R12, R13, R14: 1k; R_Axial_DIN0411_L9.9mm_D3.6mm_P12.70mm_Horizontal
SW1, SW11: SW_Left; SW_PUSH-12mm
SW2, SW12: SW_Right; SW_PUSH-12mm
SW3, SW13: SW_Increment; SW_PUSH-12mm
SW4, SW14: SW_Decrement; SW_PUSH-12mm

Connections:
+3.3Vout: IC1.2 (VOUT_1), IC11.2 (VOUT_1), SW1.1, SW2.1, SW3.1, SW4.1, SW11.1, SW12.1, SW13.1, SW14.1
+5V: IC1.3 (VIN), IC11.3 (VIN), J1.7, J2.3, J11.7, J12.3
DECREMENT: J1.4, J11.4, R4.1, R14.1, SW4.2, SW14.2
GND: IC1.1 (GROUND/ADJUST), IC11.1 (GROUND/ADJUST), J1.8, J2.4, J11.8, J12.4, R1.1, R2.1, R3.2, R4.2, R11.1, R12.1, R13.2, R14.2
INCREMENT: J1.3, J11.3, R3.1, R13.1, SW3.2, SW13.2
LEFT: J1.1, J11.1, R1.2, R11.2, SW1.2, SW11.2
RIGHT: J1.2, J11.2, R2.2, R12.2, SW2.2, SW12.2
SCL: J1.5, J2.1, J11.5, J12.1
SDA: J1.6, J2.2, J11.6, J12.2

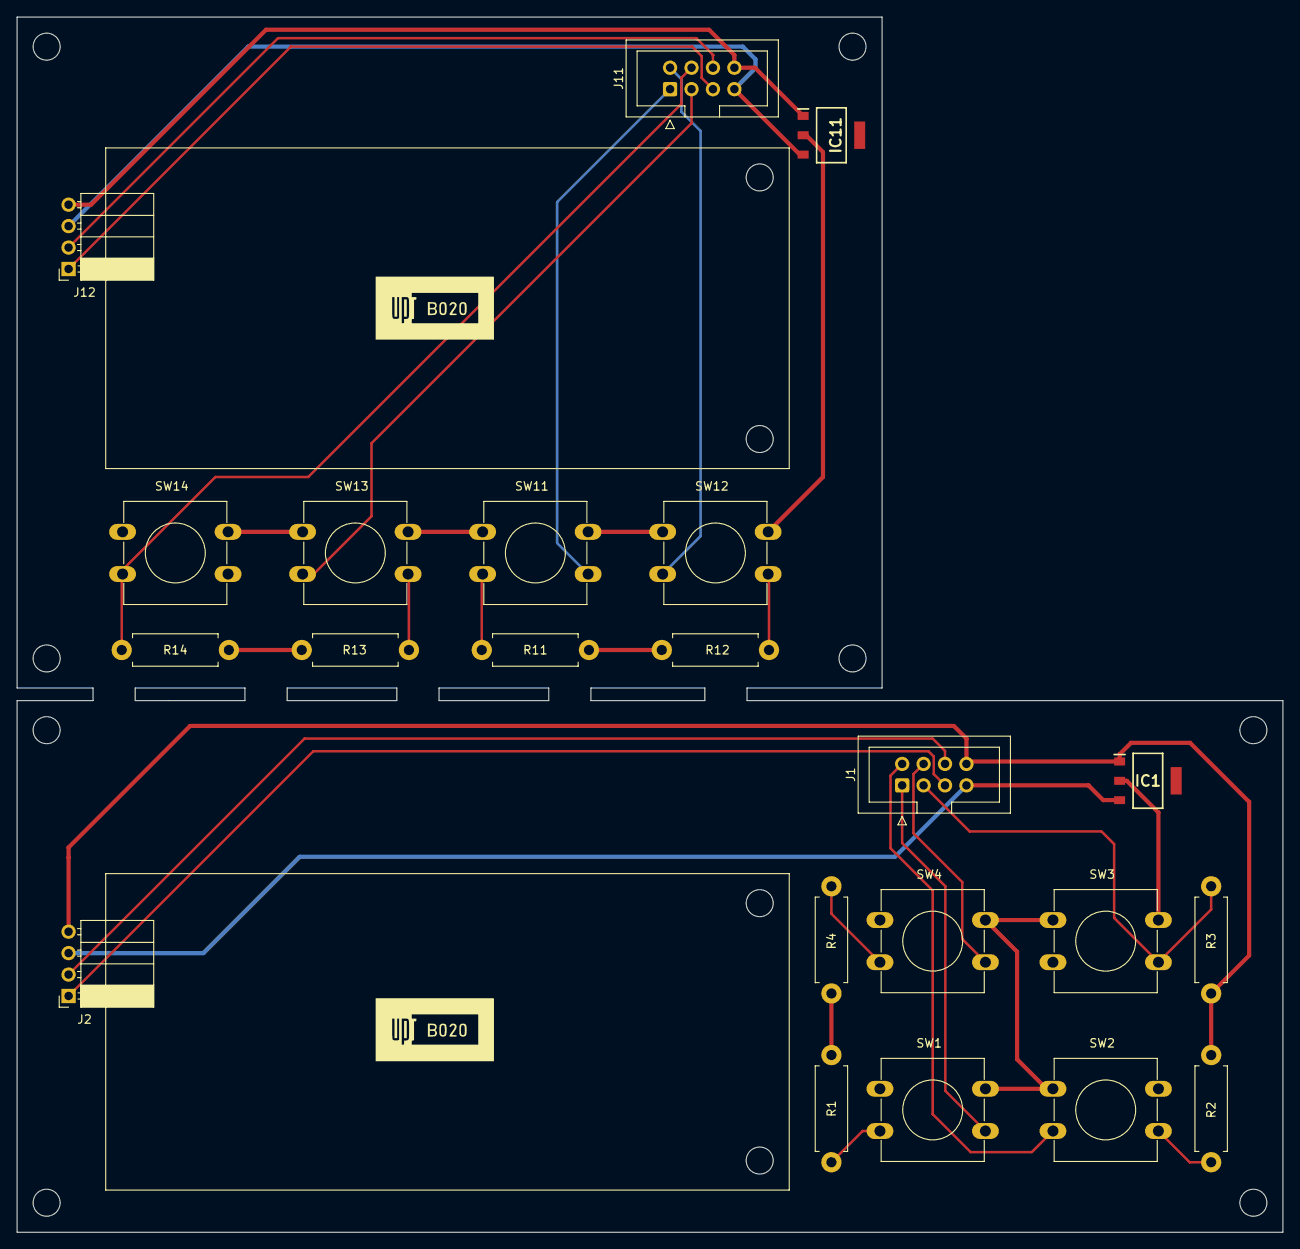
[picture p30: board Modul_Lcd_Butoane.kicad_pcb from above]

Board: 2 copper layers, 150.0 x 144.0 mm, 34 parts (0 on the bottom side), 9 nets.

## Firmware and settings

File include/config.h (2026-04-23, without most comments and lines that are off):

#define CONFIG_H
#include "SerialPortFunctions/SerialPort.hpp"
extern debix::SerialPort& serial;
#define ENABLE_CAMERA_CALIBRATION 0
#define ENABLE_CAMERA_THRESHOLD_CHECK 0
#define ENABLE_CAMERA_STREAMING 1
#define ENABLE_TCP_FRAMES 1
#define ENABLE_TCP_SITE_DEBUG 1
#define ENABLE_TEENSY_SERIAL 1
#define ENABLE_FINISH_LINE_DETECTION 0//THIS is set to 1 by timer after START_RACE
#define DEFAULT_START_RACE 0  // When set to 1 car starts
#define SERIAL_PORT "/dev/serial/by-id/usb-Teensyduino_USB_Serial_15146110-if00"
#define GPIO_CHIP "/dev/gpiochip0"
#define SW_LINE 12
#define SHM_NAME "/config_shared_memory"
#define SHM_SIZE sizeof(SharedConfig)
enum State {
    FOLLOWING_LINE = 0,
    IN_INTERSECTION,
    EXITING_INTERSECTION
};
enum InterpolatedPointsSetup {
    NEAR_VIEW_SETUP = 0,
    FAR_VIEW_SETUP
};
#pragma pack(push, 1)  // Disable struct padding
struct SharedConfig {
    int startRace;                                          //Range: 0 - 1
    int enableCarEngine;                                    //Range: 0 - 1
    int enableCarSteering;                                  //Range: 0 - 1
    int enableCameraThresholdCheck;                         //Range: 0 - 1
    int enableFinishLineDetection;                          //Range: 0 - 1
    int currentState;                                       //Range: 0 - 3
    int thresholdValue;                                     //Range: 0 - 255
    int distanceErrorFromChassis;                           //Range: -240 - 240
    int lineMinPixelCount;                                  //Range: 0 - 255
    int distanceSensorError;                                //Range: 0 - 30
    int stoppingDistanceBoxFrontEnd;                        //Range: 1 - 30
    int interpolatedPointsSetup;                            //Range: 0 - 1
    char _padding[8];
    double calibrateTopLinePerc;                            //Range: 0 - 100
    double calibrateBottomLinePerc;                         //Range: 0 - 100
    double trackLaneWidthOffset;                            //Range: -100 - 200
    double topImageCutPercentage;                           //Range: 0 - 1
    double topCutOffPercentageCustomConnected;              //Range: 0 - 1
    double lineStartPointY;                                 //Range: 0 - 1
    double line90DegreeAngleRange;                          //Range: 0 - 90
    double finishLineAngleRange;                            //Range: 90 - 180
    double servoTurnAdjustmentCoefficient;                  //Range: 0 - 5
    double corneringSpeedCoefficient;                       //Range: 0 - 2
    double minSpeed;                                        //Range: 0 - 350
    double maxSpeed;                                        //Range: 0 - 350
    double minSpeedAfterFinish;                             //Range: 0 - 350
    double maxSpeedAfterFinish;                             //Range: 0 - 350
    double currentEdfFanSpeed;                              //Range: 0 - 350
    double curvatureFactor;                                 //Range: 0 - 200
    double rdp_epsilon;                                     //Range: 0 - 25
    double boostSpeedValue;                                 //Range: 0 - 500
    double minAngleLookAheadReference;                      //Range: 0 - 180
    double maxAngleLookAheadReference;                                       //Range: 0 - 180
    double minLookAheadInCm;                                //Range: 0 - 100
    double maxLookAheadInCm;                                //Range: 0 - 100
    double waitBeforeStartSeconds;                          //Range: 0 - 10
    double waitBeforeEdfStartSeconds;                       //Range: 0 - 5
    double waitBeforeFinishDetectionSeconds;                //Range: 0 - 20
};
#pragma pack(pop)  // Restore default padding
#define DEFAULT_ENABLE_CAR_ENGINE 0
#define DEFAULT_ENABLE_CAR_STEERING 0
#define DEFAULT_THRESHOLD_VALUE 100 //75 //160
#define DEFAULT_DISTANCE_ERROR_FROM_CHASSIS 0
#define DEFAULT_LINE_MIN_PIXEL_COUNT 70
#define DEFAULT_DISTANCE_FROM_SENSOR_ERROR 10
#define DEFAULT_STOPPING_DISTANCE_BOX_FRONT_END 0
#define DEFAULT_INTERPOLATED_POINTS_SETUP 0         // 0 - Near View Setup 1 - Far View Setup (BirdEyeView)
#define DEFAULT_CALIBRATE_TOP_LINE 26.6 //41.6(percentage) //100
#define DEFAULT_CALIBRATE_BOTTOM_LINE 95.8 //95.8(percentage) //230
#define DEFAULT_TRACK_LANE_WIDTH_OFFSET 10
#define DEFAULT_TOP_IMAGE_CUT_PERCENTAGE 0.0
#define DEFAULT_BOTTOM_IMAGE_CUT_PERCENTAGE 0.35
#define DEFAULT_TOP_CUTOFF_PERCENTAGE_CUSTOM_CONNECTED 0.2 // Cuts pixels from first 45% of image
#define DEFAULT_LINE_START_POINT_Y 0.50 //0.60 // Used for intersection // birdsEyeViewHeight * lineStartPointY = Y threshold
#define DEFAULT_BOTTOM_CUTOFF_PERCENTAGE_CUSTOM_CONNECTED 1 //0.65
#define DEFAULT_LINE_90_DEGREE_ANGLE_RANGE 22.0                          // abs(degree-90) < range
#define DEFAULT_FINISH_LINE_ANGLE_RANGE 15.0
#define DEFAULT_SERVO_TURN_ADJUSTMENT_COEFFICIENT 0.8 //1.0
#define DEFAULT_CORNERING_SPEED_COEFFICIENT 1.1 //0.6
#define DEFAULT_MIN_SPEED 100 //180.0
#define DEFAULT_MAX_SPEED 150 //300.0
#define DEFAULT_MIN_SPEED_AFTER_FINISH 60.0
#define DEFAULT_MAX_SPEED_AFTER_FINISH 60.0
#define DEFAULT_EDF_FAN_CURRENT_SPEED 0.0 //350.0
#define DEFAULT_CURVATURE_FACTOR 13.0
#define DEFAULT_RDP_EPSILON 13
#define DEFAULT_BOOST_SPEED_VALUE 0.0 //55 // 25.5  //18.25
#define DEFAULT_MIN_ANGLE_LOOKAHEAD_REFERENCE 0.0
#define DEFAULT_MAX_ANGLE_LOOKAHEAD_REFERENCE 20.0
#define DEFAULT_MIN_LOOKAHEAD_IN_CM 40.0
#define DEFAULT_MAX_LOOKAHEAD_IN_CM 90.0
#define DEFAULT_WAIT_BEFORE_START_SECONDS 2.0
#define DEFAULT_WAIT_BEFORE_EDF_START_SECONDS 0.5
#define DEFAULT_WAIT_BEFORE_FINISH_DETECTION_SECONDS 7
#define DEFAULT_AFTER_FINISH_TOP_CUTOFF_PERCENTAGE_CUSTOM_CONNECTED 0.4 // Cuts pixels from first 45% of image
#define DEFAULT_EDF_FAN_AFTER_FINISH_SPEED 0.0
#define DEFAULT_TORQUE_SPEED 60;
constexpr int captureFrameWidth = 320;
constexpr int captureFrameHeight = 240;
constexpr int captureTotalPixels = captureFrameWidth * captureFrameHeight;
constexpr int resizeFrameWidth = 200;//240;//320;
constexpr int resizeFrameHeight = 150;//180;//240;
constexpr int resizeTotalPixels = resizeFrameWidth * resizeFrameHeight;
constexpr double ScalingFactor = static_cast<double>(resizeTotalPixels) / captureTotalPixels;
constexpr int  _minLinePixelCount = static_cast<int>(ScalingFactor * DEFAULT_LINE_MIN_PIXEL_COUNT);
constexpr int fitPolyWindowSize = static_cast<int>(35 * ScalingFactor);
constexpr double fitPolyEpsilon = static_cast<double>(9.0 * ScalingFactor); // Epsilon value for curve approximation
constexpr int captureFps = 100; // 120 for BUCHAREST;
const cv::Point2f undefinedPoint(0.0f, 0.0f);
constexpr int distanceBeforeIssuesAppear = 60;
constexpr double widthDstPoints = 0.45 * 320;                   // It should be a box so it has same width and height
constexpr double heightDstPoints = 0.45 * 320;                  // It should be a box so it has same width and height
constexpr double birdsEyeViewWidth = 370;
constexpr double birdsEyeViewHeight = 400;
constexpr int maxThresholdValue = 255;
constexpr double INTERSECTION_minLineLength = 45;
constexpr double IN_INTERSECTION_minLineLength = 60;
constexpr int distanceMedianFilterSampleSize = 5;
constexpr int curveSamplePoints = 12;                           // 15 Number of points to sample the curve(High number equals more complexity)
constexpr int falsePositiveCurvatureRadius = 90;               // When Calculating lookahead false Positives appear in radius Calculus
constexpr double horizontalSlopeThreshold = 1;                  // Absolute value to handle horizontal line cutoffs
constexpr double trackWidthInCm = 53.0;                         // Track Width is 53 Cm
constexpr double wheelBaseInCm = 17.0;                          // Distance between front and rear axle is 17cm
constexpr double downward_accelerationCm = 981.0;
constexpr double maxSteeringAngleDegrees = 50.0;                // Maximum steering angle in degrees either to the left or right
constexpr double maxServoAngle = 30.0;                          // Used to limit servo rotation
constexpr double maxLeftServoAngle = -30.0;                     // Used to limit servo rotation
constexpr double maxRightServoAngle = 30.0;                     // Used to limit servo rotation
constexpr double overlayFrameWeight = 0.5;                      // Used for visualization of two frames on top of eachother

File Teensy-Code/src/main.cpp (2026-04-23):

#include <Arduino.h>
#include <PWMServo.h>
#include "SteeringWheel.h"
#include <IntervalTimer.h>
#include "TFMiniPlus.h"

#define MAX(a, b) ((a) > (b) ? (a) : (b))
#define MIN(a, b) ((a) < (b) ? (a) : (b))

#define CLAMP(val, low, high) MIN(MAX(val, low), high)

TFMiniPlus tfmini;

#define BAUD_RATE  230400

#define PID_SPEED_CALIBRATION  0
   
// ================== Lidar / RADAR ==================
#define TFMINI_SERIAL Serial2                                                 // Use UART2 (Pin 7 RX, Pin 8 TX)
#define TFMINI_BAUD_RATE 115200  

#define RADAR_MOTOR_PIN  4

#define RADAR_SERVO_ANGLE_MIDDLE     70                                       // 70 middle
#define RADAR_SERVO_ANGLE_MAX_RIGHT  60                                       // 50 max right
#define RADAR_SERVO_ANGLE_MAX_LEFT   80                                       // 90 max left


// ================== Steering Servo ==================
#define STEERING_SERVO_PIN  3

#define STEERING_SERVO_ANGLE_MIDDLE     90                                    // 90 middle
#define STEERING_SERVO_ANGLE_MAX_RIGHT  60                                    // 30 max right
#define STEERING_SERVO_ANGLE_MAX_LEFT   120                                   // 120 max left

#define MAX_LIDAR_DISTANCE   500                                 

// ================== DRIVER_MOTOR ==================
//#define DRIVER_MOTOR_PIN  9
#define DRIVER_MOTOR_PIN_LEFT  6
#define DRIVER_MOTOR_PIN_RIGHT  9

#define STANDSTILL_SPEED 90.0f
#define MAX_MOTOR_SPEED 180.0f

#define FINISH_LINE_SPEED 60                                                       // cm/s
#define MAX_DESIRED_SPEED 500//215                                                 // cm/s

#define WHEEL_BASE_M 0.145f           // meters

// ================== EDF_FAN ==================
#define EDF_FAN_PIN  5

// ================== RPM Sensor ==================
//#define RPM_SENSOR_PIN  14
//#define RPM_SENSOR_PIN_LEFT  14
//#define RPM_SENSOR_PIN_RIGHT  15

#define PULSES_PER_REV  16
#define RPM_MEDIAN_FILTER_SAMPLE_SIZE  10
#define DISTANCE_PER_REVOLUTION 7                                              // Revolution = 7 cm on the ground

// ================== Emergency Remote ==================
//#define REMOTE_START_PIN 15
//#define REMOTE_STOP_PIN 16

// ================== Status LED pin ==================
#define STATUS_LED_BLUE_PIN 20
#define STATUS_LED_YELLOW_PIN 21


SteeringWheel servoSteering(STEERING_SERVO_ANGLE_MAX_LEFT, STEERING_SERVO_ANGLE_MIDDLE, STEERING_SERVO_ANGLE_MAX_RIGHT);
SteeringWheel radarServo(RADAR_SERVO_ANGLE_MAX_LEFT, RADAR_SERVO_ANGLE_MIDDLE, RADAR_SERVO_ANGLE_MAX_RIGHT);
PWMServo driverMotorRight;  
PWMServo driverMotorLeft;
PWMServo edfFan;  


volatile bool enableCarEngine = false;
volatile bool isFinishLineDetected = false;
volatile bool remoteControlOverride = false;

// Status LED
bool isBlueStatusLedOn = false;
bool isYellowStatusLedOn = false;

bool isRaceDone = false;

double lastServoAngle = 0.0;
double lastRadarAngle = 0.0;

// Driving Speed Variables
double desiredSpeed = 0;
double desiredSpeedEDF = 0;
double maxDesiredSpeed = MAX_DESIRED_SPEED;                 
//double driverMotorSpeed = STANDSTILL_SPEED;

// Radar Variables
int distanceFromLidarInCm = 10000;                                              // Something over the minimal threshold sent over Serial
uint16_t distanceBeforeIssuesAppear;
bool isRadarEnabled = false;


// Timing Variables
unsigned long previousMillisSteering = 0;
const unsigned long updateIntervalSteering = 10;                                // 20 ms(50hz) interval
unsigned long previousMillisRadar = 0;
const unsigned long updateIntervalRadar = 100;                                  // 100 ms(10hz) interval

int checksumCalc = 0;
String checksumStr;

// Timing variables for button debounce
unsigned long lastIncreaseMillis = 0;
unsigned long lastDecreaseMillis = 0;
const unsigned long debounceDelay = 200;                                        // 200 ms debounce delay

// Timing Variables for RPS
volatile unsigned long RpsLastMicros = 0;                                       // Time of the last pulse
volatile unsigned long RpsPeriodBuffer[RPM_MEDIAN_FILTER_SAMPLE_SIZE];          // Circular buffer
volatile uint8_t RpsBufferIndex = 0;                                            // Current index in buffer
// PID
double error;
double previousError = 0.0;
double integral = 0.0;
unsigned long lastPIDUpdate = 0;
const unsigned long PID_UPDATE_INTERVAL = 10;                                   // 10ms(100hz) interval for PID updates

#define Kp  0.0015                                                              // INFO: For smaller gear:0.001
#define Ki  0.0001                                                              // INFO: For smaller gear:0.0
#define Kd  0.00001                                                             // INFO: For smaller gear:0.001
#define RPS_TIMEOUT 500000                                                      // 500ms Timeout
float kp = Kp;
float ki = Ki;
float kd = Kd;

IntervalTimer lidarTimer;


void setLedStatus(int ledPin, bool isStatusLedOn);
void parseSerialInput();
void processSerialCommand(const char* command);
void emergencyStopISR();
void emergencyStartISR();
void pulseISR();
unsigned long getMedian(unsigned long *array, int size);
void updateSpeedPID(float actualSpeed, float desiredSpeed);
float speedToServoValue(float speed);
int getDistanceTfMiniPlus();
void readLidar();
int calculateRadarServoAngle(int lastServoAngle);
#if (1 == PID_SPEED_CALIBRATION)    
  void processSerialCommandPidCalibration(const char* command);
#endif
static float RearWheelTurnRadius(float wheelBase, float turnAngle);
int AngleToDirectionDeg(float angle_deg);
void SetSoftwareDifferentialSpeed(float speed_ms, float turn_radius_m, int left_right_turn, float _distanceBwWheels_m);
	

// Buffer for incoming serial data
const uint8_t SERIAL_BUFFER_SIZE = 128;
char serialBuffer[SERIAL_BUFFER_SIZE];
uint8_t serialBufferIndex = 0;


void setup() {
    
    pinMode(LED_BUILTIN, OUTPUT);
    pinMode(STATUS_LED_BLUE_PIN, OUTPUT);
    pinMode(STATUS_LED_YELLOW_PIN, OUTPUT);
    servoSteering.attach(STEERING_SERVO_PIN);   
    servoSteering.setSteeringAngleDeg(lastServoAngle); 
    
    radarServo.attach(RADAR_MOTOR_PIN);   
    radarServo.setSteeringAngleDeg(lastRadarAngle); 

    //pinMode(RPM_SENSOR_PIN, INPUT_PULLUP);
    //pinMode(REMOTE_STOP_PIN, INPUT_PULLDOWN);
    //pinMode(REMOTE_START_PIN, INPUT_PULLDOWN);

    //attachInterrupt(digitalPinToInterrupt(RPM_SENSOR_PIN), pulseISR, FALLING);
    //attachInterrupt(digitalPinToInterrupt(REMOTE_STOP_PIN), emergencyStopISR, RISING);
    //attachInterrupt(digitalPinToInterrupt(REMOTE_START_PIN), emergencyStartISR, RISING);
    
    Serial.begin(BAUD_RATE);
    TFMINI_SERIAL.begin(TFMINI_BAUD_RATE);
    while(!Serial){
      delay(10);
    }
    while(!TFMINI_SERIAL){
      delay(10);
    }
    tfmini.begin(&TFMINI_SERIAL);

    driverMotorRight.attach(DRIVER_MOTOR_PIN_RIGHT, 1148, 1832); 
    driverMotorLeft.attach(DRIVER_MOTOR_PIN_LEFT, 1148, 1832); 
    edfFan.attach(EDF_FAN_PIN, 1148, 1832); 
    
    edfFan.write(STANDSTILL_SPEED);
    delay(7000);
}
void loop() {

  digitalWrite(LED_BUILTIN, LOW);
  digitalWrite(LED_BUILTIN, HIGH);

  parseSerialInput();

  setLedStatus(STATUS_LED_BLUE_PIN, isBlueStatusLedOn);
  setLedStatus(STATUS_LED_YELLOW_PIN, isYellowStatusLedOn);

  /* static unsigned long RpsLocalBuffer[RPM_MEDIAN_FILTER_SAMPLE_SIZE];

  noInterrupts();
  for (int i = 0; i < RPM_MEDIAN_FILTER_SAMPLE_SIZE; i++) {
    RpsLocalBuffer[i] = RpsPeriodBuffer[i];
  }
  unsigned long lastPulseTime = RpsLastMicros;
  interrupts();

  unsigned long medianPeriod = getMedian(RpsLocalBuffer, RPM_MEDIAN_FILTER_SAMPLE_SIZE);

  if (micros() - lastPulseTime > RPS_TIMEOUT){
      medianPeriod = 0;
  }
  float rps = 0.0; 
  if (medianPeriod > 0) {
      // RPS = 1,000,000 us/second / (medianPeriod * pulsesPerRevolution)
      rps = (1.0e6) / ( (float)medianPeriod * (float)PULSES_PER_REV );
  }

  float actualSpeed = DISTANCE_PER_REVOLUTION * rps;
  */
 
  int distance = getDistanceTfMiniPlus();
  if (distance > 0) {
    if(distance > MAX_LIDAR_DISTANCE){
      distanceFromLidarInCm = MAX_LIDAR_DISTANCE;
    }else{
      distanceFromLidarInCm = distance;
    }
  }
  
  if(isFinishLineDetected)
  {
    if(isRadarEnabled){
      lastRadarAngle = calculateRadarServoAngle(lastRadarAngle);
    }
    else
    {
      lastRadarAngle = 0;
    }
    
    unsigned long currentMillisRadar = millis();

    if (currentMillisRadar - previousMillisRadar >= updateIntervalRadar)
    {
        previousMillisRadar = currentMillisRadar;

        radarServo.setSteeringAngleDeg(lastRadarAngle);
    }
  }

  // float writeSpeedDriverMotor = speedToServoValue(desiredSpeed);
 
  // if (writeSpeedDriverMotor >= 0) {   
  //   driverMotorRight.write(writeSpeedDriverMotor);
  //   driverMotorLeft.write(writeSpeedDriverMotor);
  // }

  float g_steering_angle_rad = lastServoAngle * M_PI / 180.0f;
  float g_rear_axe_turn_radius_m = RearWheelTurnRadius(WHEEL_BASE_M, g_steering_angle_rad);

  int steering_direction = AngleToDirectionDeg(lastServoAngle);

  SetSoftwareDifferentialSpeed(desiredSpeed / 100.0f, g_rear_axe_turn_radius_m, steering_direction, WHEEL_BASE_M);


   float writeSpeedEDF = speedToServoValue(desiredSpeedEDF);
  if (writeSpeedEDF >= 0) {   
    edfFan.write(writeSpeedEDF);
  }
 
  Serial.print(desiredSpeed);
  Serial.print(";");
  Serial.println(distanceFromLidarInCm);

  unsigned long currentMillisSteering = millis();

  if (currentMillisSteering - previousMillisSteering >= updateIntervalSteering) {
      previousMillisSteering = currentMillisSteering;

      servoSteering.setSteeringAngleDeg(lastServoAngle);
  }
  delay(1);
}


void setLedStatus(int ledPin, bool isStatusLedOn)
{
  
  if(isStatusLedOn)
  {
    digitalWrite(ledPin, HIGH);
  }
  else
  {
    digitalWrite(ledPin, LOW);
  }
}

void parseSerialInput() {

  while (Serial.available() > 0) {
    char incomingChar = Serial.read();

    if (incomingChar == '\n') {
      serialBuffer[serialBufferIndex] = '\0';
      #if (1 == PID_SPEED_CALIBRATION)
        processSerialCommandPidCalibration(serialBuffer);
      #else
        processSerialCommand(serialBuffer);
      #endif
      // Reset buffer index for the next command
      serialBufferIndex = 0;
    }
    else {
      if (serialBufferIndex < SERIAL_BUFFER_SIZE - 1) {
        serialBuffer[serialBufferIndex++] = incomingChar;
      }
    }
  }
}

// Parse the command received via serial input.
// Expected format: "<enableCarEngine>;<servoAngle>;<speed>;<isFinishLineDetected>;
//<distanceBeforeIssuesAppear>;<isRadarEnabled>;<blueStatusLed>;<yellowStatusLed>;<desiredSpeedEDF>"
// Example: "1;10.5;150.6;1;60;1;1;1;100;1350"
void processSerialCommand(const char* command) {
  // Create local copies of the data for parsing
  String inputString = String(command);
  inputString.trim();  // Remove any leading/trailing whitespace
  
  // Find the semicolon separator
  int firstSeparator = inputString.indexOf(';');
  int secondSeparator = inputString.indexOf(';', firstSeparator + 1);
  int thirdSeparator = inputString.indexOf(';', secondSeparator + 1);
  int forthSeparator = inputString.indexOf(';', thirdSeparator + 1);
  int fifthSeparator = inputString.indexOf(';', forthSeparator + 1);
  int sixthSeparator = inputString.indexOf(';', fifthSeparator + 1);
  int seventhSeparator = inputString.indexOf(';', sixthSeparator + 1);
  int eightSeparator = inputString.indexOf(';', seventhSeparator + 1);
  int lastSemicolon = inputString.indexOf(';', eightSeparator + 1);

  String payload = inputString.substring(0, lastSemicolon);
  checksumStr = inputString.substring(lastSemicolon + 1);
  checksumCalc = 0;
  for (char c : payload) {
      checksumCalc += (uint8_t)c;
  }

  //if (checksumCalc == checksumStr.toInt()) 
  if (true)
  {
    if (firstSeparator != -1 && secondSeparator != -1 && thirdSeparator != -1
        && forthSeparator != -1 && fifthSeparator != -1 && sixthSeparator != -1 
        && seventhSeparator != -1 && eightSeparator != -1 && lastSemicolon != -1) {

      // If car is not stopped via Remote 
      if(!remoteControlOverride){
        String enableCarEngineString = inputString.substring(0, firstSeparator);
        enableCarEngine = enableCarEngineString.toInt();
      }

      String angleString = inputString.substring(firstSeparator + 1, secondSeparator);
      lastServoAngle = angleString.toFloat();

      String speedString = inputString.substring(secondSeparator + 1, thirdSeparator);
      desiredSpeed = speedString.toFloat();
      desiredSpeed = desiredSpeed > 0 ? (desiredSpeed < maxDesiredSpeed ? desiredSpeed :maxDesiredSpeed) : 0;

      
      String finishLineString = inputString.substring(thirdSeparator + 1, forthSeparator);
      if(1 == finishLineString.toInt())
      {
        isFinishLineDetected = true;
      }else{
        isFinishLineDetected = false;
      }

      String stringDistanceIssues = inputString.substring(forthSeparator + 1, fifthSeparator);
      distanceBeforeIssuesAppear = stringDistanceIssues.toInt();

      String stringIsRadarEnabled = inputString.substring(fifthSeparator + 1, sixthSeparator);
      if (1 == stringIsRadarEnabled.toInt())
      {
        isRadarEnabled = true;
      }
      else
      {
        isRadarEnabled = false;
      }

      String blueStatusLedString = inputString.substring(sixthSeparator + 1, seventhSeparator);
      if (1 == blueStatusLedString.toInt())
      {
        isBlueStatusLedOn = true;
      }
      else
      {
        isBlueStatusLedOn = false;
      }

      String yellowStatusLedString = inputString.substring(seventhSeparator + 1, eightSeparator);
      if (1 == yellowStatusLedString.toInt())
      {
        isYellowStatusLedOn = true;
      }
      else
      {
        isYellowStatusLedOn = false;
      }

      String speedStringEDF = inputString.substring(eightSeparator + 1, lastSemicolon);
      desiredSpeedEDF = speedStringEDF.toFloat();
      desiredSpeedEDF = desiredSpeedEDF > 0 ? (desiredSpeedEDF < maxDesiredSpeed ? desiredSpeedEDF :maxDesiredSpeed) : 0;
      
    }
  }
}

#if (1 == PID_SPEED_CALIBRATION)    
  void processSerialCommandPidCalibration(const char* command) {
  // Create local copies of the data for parsing
  String inputString = String(command);
  inputString.trim();  // Remove any leading/trailing whitespace

  
  // Find the semicolon separator
  int firstSeparator = inputString.indexOf(';');
  int secondSeparator = inputString.indexOf(';', firstSeparator + 1);
  int thirdSeparator = inputString.indexOf(';', secondSeparator + 1);
  int forthSeparator = inputString.indexOf(';', thirdSeparator + 1);

  if (firstSeparator != -1 && secondSeparator != -1 && thirdSeparator != -1
      && forthSeparator != -1) {

    String angleString = inputString.substring(0, firstSeparator);
    lastServoAngle = angleString.toFloat();

    String speedString = inputString.substring(firstSeparator + 1, secondSeparator);
    desiredSpeed = speedString.toFloat();
    desiredSpeed = desiredSpeed > 0 ? (desiredSpeed < maxDesiredSpeed ? desiredSpeed :maxDesiredSpeed) : 0;

    String kpString = inputString.substring(secondSeparator + 1, thirdSeparator);
    kp = kpString.toFloat();

    String kiString = inputString.substring(thirdSeparator + 1, forthSeparator);
    ki = kiString.toFloat();
    
    String kdString = inputString.substring(forthSeparator + 1);
    kd = kdString.toFloat();
  }
  else {
    // Used for Quick test (e.g. 105.5)
    desiredSpeed = inputString.toFloat();
    desiredSpeed = desiredSpeed > 0 ? (desiredSpeed < maxDesiredSpeed ? desiredSpeed :maxDesiredSpeed) : 0;
  }
}
#endif

void emergencyStopISR() {
    remoteControlOverride = true;
    enableCarEngine = false;
    desiredSpeed = 0;
    driverMotorRight.write(STANDSTILL_SPEED);
    driverMotorLeft.write(STANDSTILL_SPEED);
}

void emergencyStartISR() {
    enableCarEngine = true;
    remoteControlOverride = false;
}

void pulseISR() {
  unsigned long currentMicros = micros();
  unsigned long newPeriod = currentMicros - RpsLastMicros;
  RpsLastMicros = currentMicros;
  if (newPeriod < 100) {  // 100 µs is arbitrary; tweak as needed
    return; 
  }
  RpsPeriodBuffer[RpsBufferIndex] = newPeriod;
  RpsBufferIndex = (RpsBufferIndex + 1) % RPM_MEDIAN_FILTER_SAMPLE_SIZE;
}

unsigned long getMedian(unsigned long *array, int size) {
  // Simple bubble sort
  for (int i = 0; i < size - 1; i++) {
    for (int j = i + 1; j < size; j++) {
      if (array[j] < array[i]) {
        unsigned long temp = array[i];
        array[i] = array[j];
        array[j] = temp;
      }
    }
  }
  
  // Return middle element
  if (size % 2 == 1) {
    return array[size / 2];
  } else {
    int mid = size / 2;
    return (array[mid - 1] + array[mid]) / 2;
  }
}

/*void updateSpeedPID(float actualSpeed, float desiredSpeed) {
    unsigned long currentMillis = millis();
    if (currentMillis - lastPIDUpdate < PID_UPDATE_INTERVAL) {
        return; // Run PID at a fixed interval
    }
    lastPIDUpdate = currentMillis;

    error = desiredSpeed - actualSpeed;

    float P = kp * error;

    integral += error * (PID_UPDATE_INTERVAL / 1000.0);
    integral = constrain(integral, -50, 50);

    float I = ki * integral;

    float derivative = (error - previousError) / (PID_UPDATE_INTERVAL / 1000.0);
    float D = kd * derivative;

    previousError = error;

    float pidOutput = P + I + D;
    driverMotorSpeed += pidOutput;
    driverMotorSpeed = constrain(driverMotorSpeed, STANDSTILL_SPEED, MAX_MOTOR_SPEED);

    if (enableCarEngine) {
        driverMotor.write(driverMotorSpeed);
    } else {
        driverMotor.write(STANDSTILL_SPEED);
    }
}
*/
// float speedToServoValue(float speed) {
//   if (speed <= 0) return STANDSTILL_SPEED;
  
//   float a = -0.0020;
//   float b = 13.9775;
//   float c = -1263.7335 - speed;
  
//   float discriminant = b * b - 4 * a * c;
//   if (discriminant < 0) {
//     // No real solution
//     return -1;
//   }

//   // Use the '+' branch since servo value increases with speed
//   float servoValue = (-b + sqrt(discriminant)) / (2 * a);
//   return servoValue;
// }

int floatCmp(float a, float b)
{
    const float abs_epsilon = 1e-6f;
    const float rel_epsilon = 1e-5f;

    // NaN handling
    if (isnan(a) || isnan(b))
        return 0;   // sau poți decide alt comportament

    // Handle infinities explicitly
    if (isinf(a) || isinf(b))
    {
        if (a == b) return 0;
        return (a < b) ? -1 : 1;
    }

    // Handle exact equality (+0 vs -0 included)
    if (a == b)
        return 0;

    float diff = a - b;
    float abs_diff = fabsf(diff);

    // Absolute tolerance
    if (abs_diff <= abs_epsilon)
        return 0;

    // Relative tolerance
    float max_ab = fmaxf(fabsf(a), fabsf(b));
    if (abs_diff <= max_ab * rel_epsilon)
        return 0;

    return (diff < 0.0f) ? -1 : 1;
}

static float RearWheelTurnRadius(float wheelBase, float turnAngle) {
	float angle;
	//float temp_sin = sinf(turnAngle);
	if (floatCmp(turnAngle, 0.0f) == 0) {
		return -1.0f;
	}
	float temp_sin = tanf(turnAngle);
	if (floatCmp(temp_sin, 0.0f) == 0) {
		return 0.0f;
	}

	//angle = (wheelBase / tanf(turnAngle));
	angle = (wheelBase / temp_sin);

	angle = fabsf(angle);
	return angle;
}

// maxLeft:30 ; maxRight:-30
// -1: left, 0: forward, 1: right
	int AngleToDirectionDeg(float angle_deg) {
		int cmp_result = floatCmp(angle_deg, 0.0);
		if (cmp_result > 0) {
			return 1;
		}
		else if (cmp_result < 0.0) {
			return -1;
		}
		else {
			return 0;
		}
	}


// left_right_turn: negative if turning left, positive if turning right
void SetSoftwareDifferentialSpeed(float speed_ms, float turn_radius_m, int left_right_turn, float _distanceBwWheels_m){
		float left_wheel_turn_radius;
		float right_wheel_turn_radius;
		float left_wheel_turn_circonference;
		float right_wheel_turn_circonference;
		float car_turn_circumference;
		float left_wheel_speed_request_m;
		float right_wheel_speed_request_m;

		turn_radius_m = fabs(turn_radius_m);

		if (floatCmp(turn_radius_m, 0.0) == 0 || left_right_turn == 0)	// going straight
		{
			left_wheel_speed_request_m = speed_ms;
			right_wheel_speed_request_m = speed_ms;
		}
		else{
			if (left_right_turn < 0)	// left turn
			{
				left_wheel_turn_radius = turn_radius_m - (_distanceBwWheels_m / 2.0);
				right_wheel_turn_radius = turn_radius_m + (_distanceBwWheels_m / 2.0);
			}
			else if (left_right_turn > 0)	// right turn
			{
				left_wheel_turn_radius = turn_radius_m + (_distanceBwWheels_m / 2.0);
				right_wheel_turn_radius = turn_radius_m - (_distanceBwWheels_m / 2.0);
			}

			left_wheel_turn_circonference = (2.0 * left_wheel_turn_radius) * M_PI;
			right_wheel_turn_circonference = (2.0 * right_wheel_turn_radius) * M_PI;
			car_turn_circumference = (2.0 * turn_radius_m) * M_PI;
			
			left_wheel_speed_request_m =(left_wheel_turn_circonference / car_turn_circumference) * speed_ms;
			right_wheel_speed_request_m =(right_wheel_turn_circonference / car_turn_circumference) * speed_ms;
		}
		

  float left_motor_speed_raw = speedToServoValue(left_wheel_speed_request_m * 100.0f);
  float right_motor_speed_raw = speedToServoValue(right_wheel_speed_request_m * 100.0f);

 
    driverMotorRight.write(right_motor_speed_raw);
    driverMotorLeft.write(left_motor_speed_raw);
	}
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

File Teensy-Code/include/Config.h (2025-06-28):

/*
* Copyright 2023 Constantin Dumitru Petre RĂDULICEA
* 
* Licensed under the Apache License, Version 2.0 (the "License");
* you may not use this file except in compliance with the License.
* You may obtain a copy of the License at
* 
*   http://www.apache.org/licenses/LICENSE-2.0
* 
* Unless required by applicable law or agreed to in writing, software
* distributed under the License is distributed on an "AS IS" BASIS,
* WITHOUT WARRANTIES OR CONDITIONS OF ANY KIND, either express or implied.
* See the License for the specific language governing permissions and
* limitations under the License.
*/



//All defines and Includes

/*
CAR1 FULL JUICE baterie mica
enable_car_engine = 0.0;
enable_car_steering_wheel = 1.0;
enable_emergency_brake = 1.0;
enable_pixy_vector_approximation = 0.0;             
enable_distance_sensor1 = 1.0;
enable_distance_sensor2 = 1.0;
enable_distance_sensor3 = 1.0;

lane_width_vector_unit_real = 53.0;
black_color_treshold = 0.2;
car_length_cm = 17.5;
lookahead_min_distance_cm = 16.0;                       % 22
lookahead_max_distance_cm = 40.0;                       % 40
min_speed = 97.0;
max_speed = 115.0;                                      % 
emergency_break_distance_cm = 75.0;                     % 75
emergency_brake_min_speed = 94.0;
emergency_brake_distance_from_obstacle_cm = 14.0;       % 14
emergency_brake_enable_delay = 0.0;
steering_wheel_angle_offset = 0.0;

*/

#ifndef __CONFIG_H__
#define __CONFIG_H__

#define CAR1 1
#define DEBUG_MODE 1
#define RACE_MODE 0
#define TEMP_MODE 0

/*====================================================================================================================================*/
static int enable_car_engine = 0;
static int enable_car_steering_wheel = 0;
static int enable_emergency_brake = 1;
static int enable_pixy_vector_approximation_soft = 0;
static int enable_distance_sensor1_soft = 1;
static int enable_remote_start_stop_soft = 0;
static int enable_finish_line_detection_soft = 1;
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

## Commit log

2024-11-12 Vision code that runs with ELP usb camera
2024-12-09 working with frame overlay
2024-12-12 (working)previous solution had problems with push
    [config.h, main.cpp]
2024-12-12 added Steering angle in degrees
2024-12-18 added C++ classes and mapped Servo angle
2024-12-26 slow but working servo
2025-02-08 (fix) Reorganized config file structure
    [PurePursuit.hpp, config.h]
2025-03-16 (feat + fix) intersection - fixed one line mirroring with mirroring function - added new speed formula - added state machine
    [PurePursuit.hpp, config.h, main.cpp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]
2025-03-28 (fix) fixed k min k max
    - Flashed BlHeliS
    - Added Status LED
    - Time on track 9.4s with lookahead 50cm/50cm
    [PurePursuit.hpp, config.h, main.cpp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]
2025-04-07 (feat) 8,795s clean run
    - Fixed intersection bugs
    - Can go more laps repeatedly without miss
    - Added boot up start
    [config.h, main.cpp, menu_rotary.py]
2025-04-12 (feat)Speed Fix and Initial line Jiggle
    [PurePursuit.hpp, config.h, main.cpp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]
2025-04-29 (feat) finish line working - need to fix 350 edf after finish
    [CameraProcessing.cpp, PurePursuit.cpp, PurePursuit.hpp]
2025-05-02 (fix) last working update with edf fix and good speed
    [CameraProcessing.cpp, config.h, main.cpp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]
2025-05-04 9.7s official run with box stop ( still check blue led)
2025-06-28 added teensy code
    [90 degrees joint.dwg, 90 degrees joint_1.stl, 90 degrees joint_2.stl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]
